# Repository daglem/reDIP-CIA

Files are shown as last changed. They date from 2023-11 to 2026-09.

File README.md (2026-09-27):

# reDIP CIA

## MOS 6520 PIA / MOS 6522 VIA / MOS 6526/8520/8521 CIA FPGA replacement
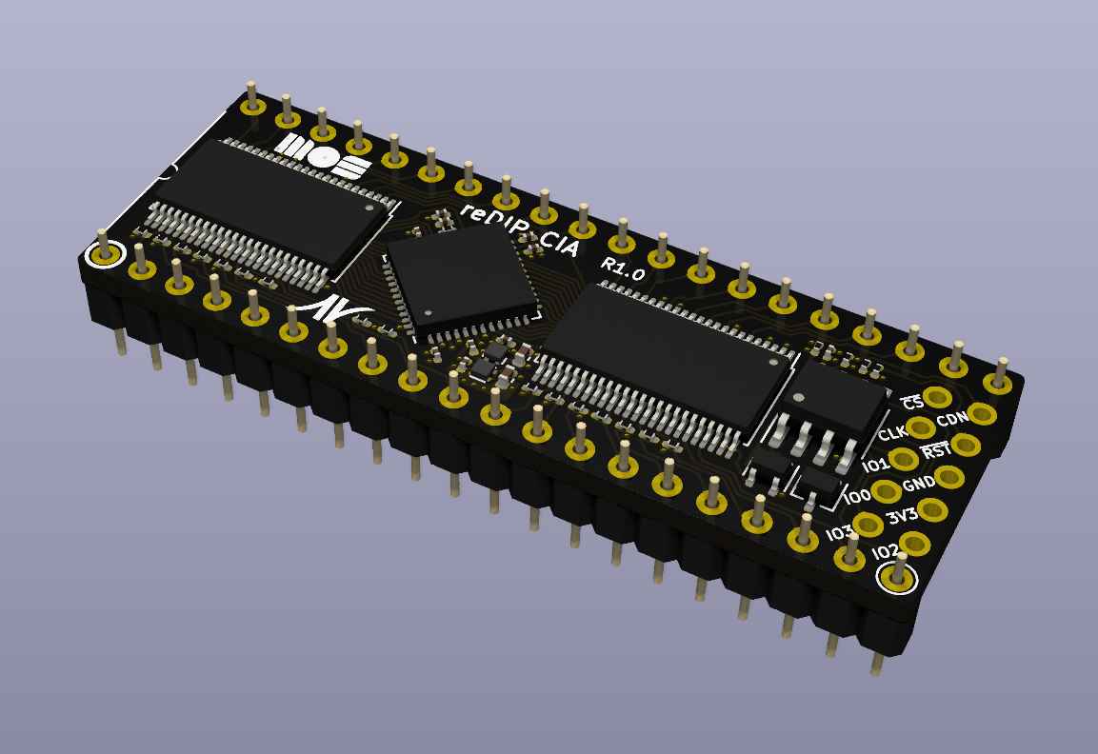
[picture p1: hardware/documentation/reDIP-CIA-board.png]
Board


## Overview
The reDIP CIA is an open source FPGA board which combines the following in a
DIP-40 size package:

* Lattice iCE5LP1K FPGA
* 1Mbit FLASH
* 5V tolerant I/O

The reDIP CIA provides an open source hardware platform for MOS 6520 PIA /
MOS 6522 VIA / MOS 6526/8520/8521 CIA replacements.

Designs for the iCE5LP1K FPGA can be processed by
[yosys](https://github.com/YosysHQ/yosys/) and
[nextpnr](https://github.com/YosysHQ/nextpnr/).

## I/O interfaces

### DIP-40 header pins:

* 5V input
* 35 FPGA GPIO
* 3 FPGA open-drain I/O
* GND

All FPGA header I/O is 5V tolerant, and can drive 5V TTL.

### SPI / programming header:

A separate header footprint is provided for (Q)SPI flash programming, with
pinout borrowed from the
[iCEBreaker Bitsy](https://codeberg.org/icebreaker-fpga/icebreaker).

## MOS 6526/8521 and MOS 8520 CIA compatibility

The board is fully pin compatible with the venerable MOS 6526/8521 and MOS 8520
CIA chips.

Cycle accurate emulation of the MOS 6526/8521 and MOS 8520 CIA chips has been
implemented in [gateware](gateware/CIA/), configurable via [software](software/).

## MOS 6522 VIA compatibility

Cycle accurate emulation of the MOS 6522 VIA chip has been implemented in
[gateware](gateware/VIA/).

## MOS 6520 PIA compatibility

Cycle accurate emulation of the MOS 6520 PIA chip has been implemented in
[gateware](gateware/PIA/).

## Thanks

The gateware implementations would not have been possible without the
[outstanding work](https://6502.org/forum/viewtopic.php?t=7427) on varius MOS
chips by Frank "androSID" Wolf and Dieter "ttlworks" Müller.

Wagner Rodriguez has tested the 8520 CIA implementation with the [Versatile
Amiga Testprogram](https://aminet.net/package/util/misc/VATestprogram).

Mateusz Nalewajski has hunted down and fixed two bugs while working on
integrating the VIA gateware in
[icepi-zero-c64](https://github.com/m1nl/icepi-zero-c64).

André Fachat has tested the VIA and PIA implementations with his [PET PIA and
VIA test suite](https://github.com/fachat/pet_viapia_tests).

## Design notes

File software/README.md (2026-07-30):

# reDIP CIA software

## CIA model configuration
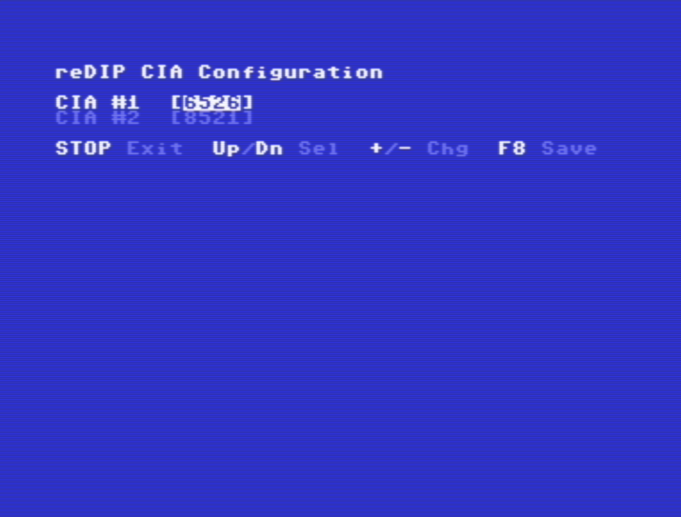
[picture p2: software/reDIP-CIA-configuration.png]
Configuration


The supplied [C64 program](cia-config.prg) can be used to select between MOS6526 and MOS8521 emulation for reDIP CIA boards in C64 and C128 machines.

The configuration is stored in the on-board flash chips.

The detected chip model is also displayed for original CIA chips.

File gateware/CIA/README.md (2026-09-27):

# reDIP CIA gateware

## Description

The reDIP CIA FPGA gateware provides cycle exact CIA emulation for the
[reDIP CIA](https://github.com/daglem/reDIP-CIA) hardware.

The gateware implementation is based on the excellent schematics of the
[MOS 8520](https://6502.org/forum/viewtopic.php?f=4&t=7368) and
[MOS 8521](https://6502.org/forum/viewtopic.php?f=4&t=7418) chips provided by
Frank "androSID" Wolf and Dieter "ttlworks" Müller.

Please note that the internal pullups for CNT, /FLAG, SP, and TOD in a real
8520 chip are only emulated by weak ~100k internal FPGA pullups.

By default, emulation of MOS 6526/8521 and MOS 8520 CIA chips is configurable
via [software](/software/), initially
configured as MOS 8521.

The emulation can alternatively be locked down at build time via one of

* `make MOS6526`
* `make MOS8521`
* `make MOS8520`

With projects in mind which use the reDIP CIA core gateware as part of a larger
whole to emulate the Commmodore 64, there is also an option to disable code for
the MOS 8520 (used in Commodore Amiga computers and 1581 disk drives). This
frees up some FPGA resources:

* `make NO_MOS8520`

## Installation

The gateware is built via `make` (see above) and may be installed on the reDIP
CIA hardware e.g. using an
[FTDI cable](https://ftdichip.com/products/c232hm-ddhsl-0-2/).

The gateware can be installed via `make prog`, which programs the on-board
flash chip via `iceprog`. Note that this makes configurable gateware generated
by `make` or `make NO_MOS8520` default to MOS 8521. The default can
alternatively be specified via one of

* `make prog-MOS6526`  # C64, SX-64, Ultimax
* `make prog-MOS8521`  # C64, C128, 1570, 1571
* `make prog-MOS8520`  # Amiga, 1581

## License

This gateware is part of reDIP CIA, a MOS 6526/8520/8521 CIA FPGA emulation
platform.\
Copyright (C) 2025 - 2026  Dag Lem \<resid@nimrod.no\>

The source describes Open Hardware and is licensed under the CERN-OHL-S v2.

You may redistribute and modify the source and make products using it under
the terms of the [CERN-OHL-S v2](https://ohwr.org/cern_ohl_s_v2.txt).

This source is distributed WITHOUT ANY EXPRESS OR IMPLIED WARRANTY,
INCLUDING OF MERCHANTABILITY, SATISFACTORY QUALITY AND FITNESS FOR A
PARTICULAR PURPOSE. Please see the CERN-OHL-S v2 for applicable conditions.

Source location:
[https://github.com/daglem/reDIP-CIA](https://github.com/daglem/reDIP-CIA)

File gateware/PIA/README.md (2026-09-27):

# reDIP PIA gateware

## Description

The reDIP PIA FPGA gateware provides cycle exact PIA emulation for the
[reDIP CIA](https://github.com/daglem/reDIP-CIA) hardware.

The gateware implementation is based on the excellent schematics of the
[MOS 6520](https://6502.org/forum/viewtopic.php?f=4&t=7425) chip provided by
Frank "androSID" Wolf and Dieter "ttlworks" Müller.

Please note that the internal pullup for CA2 in a real PIA chip is only
emulated by a weak ~100k internal FPGA pullup.

## Installation

The gateware is built via `make` and may be installed on the reDIP CIA hardware
e.g. via `make prog` using an
[FTDI cable](https://ftdichip.com/products/c232hm-ddhsl-0-2/).

## License

This gateware is part of reDIP CIA, a MOS PIA/VIA/CIA FPGA emulation
platform.\
Copyright (C) 2025 - 2026  Dag Lem \<resid@nimrod.no\>

The source describes Open Hardware and is licensed under the CERN-OHL-S v2.

You may redistribute and modify the source and make products using it under
the terms of the [CERN-OHL-S v2](https://ohwr.org/cern_ohl_s_v2.txt).

This source is distributed WITHOUT ANY EXPRESS OR IMPLIED WARRANTY,
INCLUDING OF MERCHANTABILITY, SATISFACTORY QUALITY AND FITNESS FOR A
PARTICULAR PURPOSE. Please see the CERN-OHL-S v2 for applicable conditions.

Source location:
[https://github.com/daglem/reDIP-CIA](https://github.com/daglem/reDIP-CIA)

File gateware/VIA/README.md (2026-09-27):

# reDIP VIA gateware

## Description

The reDIP VIA FPGA gateware provides cycle exact VIA emulation for the
[reDIP CIA](https://github.com/daglem/reDIP-CIA) hardware.

The gateware implementation is based on the excellent schematics of the
[MOS 6522](https://6502.org/forum/viewtopic.php?f=4&t=7241) chip provided by
Frank "androSID" Wolf and Dieter "ttlworks" Müller.

Please note that the internal pullups for CA2, CB1, and CB2 in a real VIA chip
are only emulated by weak ~100k internal FPGA pullups.

## Installation

The gateware is built via `make` and may be installed on the reDIP CIA hardware
e.g. via `make prog` using an
[FTDI cable](https://ftdichip.com/products/c232hm-ddhsl-0-2/).

## License

This gateware is part of reDIP CIA, a MOS PIA/VIA/CIA FPGA emulation
platform.\
Copyright (C) 2025 - 2026  Dag Lem \<resid@nimrod.no\>

The source describes Open Hardware and is licensed under the CERN-OHL-S v2.

You may redistribute and modify the source and make products using it under
the terms of the [CERN-OHL-S v2](https://ohwr.org/cern_ohl_s_v2.txt).

This source is distributed WITHOUT ANY EXPRESS OR IMPLIED WARRANTY,
INCLUDING OF MERCHANTABILITY, SATISFACTORY QUALITY AND FITNESS FOR A
PARTICULAR PURPOSE. Please see the CERN-OHL-S v2 for applicable conditions.

Source location:
[https://github.com/daglem/reDIP-CIA](https://github.com/daglem/reDIP-CIA)

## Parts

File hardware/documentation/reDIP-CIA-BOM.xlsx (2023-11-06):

Prj: | reDIP CIA |  |  |  |  |  |  | Board Qty: | 100
Co.: | Nimrod |  |  |  |  |  |  | Unit Cost: | $5.31
Prj date: | Mon 06 Nov 2023 10:01:10 PM CET |  |  |  |  |  |  | Total Cost: | $531.05 |  |  |  |  | $547.89 | 14 of 16 parts found |  |  |  |  | $536.10 | 15 of 16 parts found
$ date: | 2023-11-06 22:01:11
Global Part Info |  |  |  |  |  |  |  |  |  | Digi-Key |  |  |  |  |  | Mouser
Refs | Value | Desc | Notes | Footprint | Manf | Manf# | Qty | Unit$ | Ext$ | Avail | Purch | Unit$ | MOQ | Ext$ | Cat# | Avail | Purch | Unit$ | MOQ | Ext$ | Cat#
C1,C3 | 1uF | CAP CER 2.2uF 16V 10% X6S 0402 | 5V DC DERATED TO 1uF | C_0402_1005Metric | Murata | GRM155C81C225KE11D (https://www.murata.com/products/productdetail.aspx?partno=GRM155C81C225KE11D) | 200 | $0.088 | $17.66 | 66508 |  | $0.088 | 1 | $17.66 | 490-14595-1-ND (https://www.digikey.com/en/products/detail/murata-electronics/GRM155C81C225KE11D/4905093) | 57211 |  | $0.089 | 1 | $17.80 | 81-GRM155C81C225KE1D (https://no.mouser.com/ProductDetail/Murata-Electronics/GRM155C81C225KE11D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)
C2,C11 | 1uF | CAP CER 1uF 6.3V 20% X6S 0201 | 1.2V DC | C_0201_0603Metric | Murata | GRM033C80J105ME05D (https://www.murata.com/products/productdetail.aspx?partno=GRM033C80J105ME05D) | 200 | $0.054 | $10.80 | 1440111 |  | $0.078 | 1 | $15.56 | 490-13218-1-ND (https://www.digikey.com/en/products/detail/murata-electronics/GRM033C80J105ME05D/5877381) | 777764 |  | $0.054 | 1 | $10.80 | 81-GRM033C80J105ME5D (https://no.mouser.com/ProductDetail/Murata-Electronics/GRM033C80J105ME05D?qs=P8zzrVhehaso8Xg5mhsu3Q%3D%3D)
C4 | 1uF | CAP CER 2.2uF 10V 20% X5R 0201 | 3.3V DC DERATED TO 1uF | C_0201_0603Metric | Murata | GRM035R61A225ME01D (https://www.murata.com/products/productdetail.aspx?partno=GRM035R61A225ME01D) | 100 |  |  |  |  |  |  |  |  | NonStk |  |  | 10000 |  | 81-GRM035R61A225ME1D (https://no.mouser.com/ProductDetail/Murata-Electronics/GRM035R61A225ME01D?qs=pUKx8fyJudAGsIsikE8KgA%3D%3D)
C5-C10,C12 | 0.1uF | CAP CER 0.22uF 6.3V 20% X5R 0201 | C8: 1.2V DC DERATED TO 0.1uF C5-C7,C9,C10,C12: 3.3V DC DERATED TO 0.1uF | C_0201_0603Metric | Murata | GRM033R60J224ME90D (https://www.murata.com/products/productdetail.aspx?partno=GRM033R60J224ME90D) | 700 | $0.006 | $4.24 | 14729 |  | $0.006 | 1 | $4.24 | 490-11973-1-ND (https://www.digikey.com/en/products/detail/murata-electronics/GRM033R60J224ME90D/4904674) | 84464 |  | $0.007 | 1 | $4.90 | 81-GRM033R60J224ME9D (https://no.mouser.com/ProductDetail/Murata-Electronics/GRM033R60J224ME90D?qs=2W5sgKM%2F3704nCcQ8ai7mA%3D%3D)
D1 | BAS16W | DIODE Vf=715mV If=1mA | Replacement parts: BAS16W SOT-323/SC-70 | SOT-323_SC-70 | Diodes | BAS16W-7-F (https://www.diodes.com/assets/Datasheets/MMBD4148W_BAS16W.pdf) | 100 | $0.057 | $5.70 | 43800 |  | $0.073 | 1 | $7.33 | BAS16W-FDICT-ND (https://www.digikey.com/en/products/detail/diodes-incorporated/BAS16W-7-F/814988) | 21552 |  | $0.057 | 1 | $5.70 | 621-BAS16W-F (https://no.mouser.com/ProductDetail/Diodes-Incorporated/BAS16W-7-F?qs=Kn7RVldD90CMqWoFVqNeZQ%3D%3D)
J1,J2 | Conn_01x20 | CONN HDR CIRCULAR PIN 0.5mm 20 POS .100" GOLD MATING 3mm TAIL 3mm | Replacement parts: XKB X5511WV-20-C396D43-1220, other similar hdr circular pin ~0.5mm | PinHeader_1x20_P2.54mm_Vertical_Machined | XKB | X5511WV-20-C35D35-1000 (https://www.helloxkb.com/Home/Goods/goodsInfo/id/72370.html) | 200
R1-R16 | 4.7k | RES 4.7kΩ 50mW 5% 0201 |  | R_0201_0603Metric | Panasonic | ERJ1GNJ472C (https://industrial.panasonic.com/ww/products/pt/general-purpose-chip-resistors/models/ERJ1GNJ472C) | 1600 | $0.006 | $9.58 | 46 |  | $0.006 | 1 | $9.58 | P4.7AECT-ND (https://www.digikey.com/en/products/detail/panasonic-electronic-components/ERJ-1GNJ472C/2035803) | 273867 |  | $0.007 | 1 | $11.20 | 667-ERJ-1GNJ472C (https://no.mouser.com/ProductDetail/Panasonic/ERJ-1GNJ472C?qs=wTZ%2FFzl837bAY5BVQWuQGQ%3D%3D)
R17,R21 | 2.87k | RES 2.87kΩ 50mW 1% 0201 |  | R_0201_0603Metric | Panasonic | ERJ1GNF2871C (https://industrial.panasonic.com/ww/products/pt/general-purpose-chip-resistors/models/ERJ1GNF2871C) | 200 | $0.014 | $2.80 | 104225 |  | $0.019 | 1 | $3.80 | P122901CT-ND (https://www.digikey.com/en/products/detail/panasonic-electronic-components/ERJ-1GNF2871C/2036162) | 28194 |  | $0.014 | 1 | $2.80 | 667-ERJ-1GNF2871C (https://no.mouser.com/ProductDetail/Panasonic/ERJ-1GNF2871C?qs=nuXzIS8loXEy0KxXtNZxEA%3D%3D)
R18 | 100 | RES 100Ω 50mW 5% 0201 |  | R_0201_0603Metric | Panasonic | ERJ1GNJ101C (https://industrial.panasonic.com/ww/products/pt/general-purpose-chip-resistors/models/ERJ1GNJ101C) | 100 | $0.007 | $0.70 | 231675 |  | $0.013 | 1 | $1.25 | P123220CT-ND (https://www.digikey.com/en/products/detail/panasonic-electronic-components/ERJ-1GNJ101C/2035763) | 91154 |  | $0.007 | 1 | $0.70 | 667-ERJ-1GNJ101C (https://no.mouser.com/ProductDetail/Panasonic/ERJ-1GNJ101C?qs=nuXzIS8loXGN5So4aOOV1Q%3D%3D)
R19,R20 | 10k | RES 10kΩ 50mW 5% 0201 |  | R_0201_0603Metric | Panasonic | ERJ1GNJ103C (https://industrial.panasonic.com/ww/products/pt/general-purpose-chip-resistors/models/ERJ1GNJ103C) | 200 | $0.013 | $2.66 | 704515 |  | $0.013 | 1 | $2.66 | P123222CT-ND (https://www.digikey.com/en/products/detail/panasonic-electronic-components/ERJ-1GNJ103C/2035811) | 683736 |  | $0.014 | 1 | $2.80 | 667-ERJ-1GNJ103C (https://no.mouser.com/ProductDetail/Panasonic/ERJ-1GNJ103C?qs=nuXzIS8loXEEFlX40uqTHQ%3D%3D)
U1 | NCP115AMX120TCG | IC REG LDO 1.2V 300mA XDFN4 |  | CASE_711AJ_1.0x1.0mm_P0.65mm | onsemi | NCP115AMX120TCG (https://www.onsemi.com/pdf/datasheet/ncp115-d.pdf) | 100 | $0.118 | $11.80 | 7412 |  | $0.143 | 1 | $14.33 | NCP115AMX120TCGOSCT-ND (https://www.digikey.com/en/products/detail/onsemi/NCP115AMX120TCG/9829201) | 11436 |  | $0.118 | 1 | $11.80 | 863-NCP115AMX120TCG (https://no.mouser.com/ProductDetail/onsemi/NCP115AMX120TCG?qs=l7cgNqFNU1iSEavmMXBgHw%3D%3D)
U2 | NCP115AMX330TCG | IC REG LDO 3.3V 300mA XDFN4 |  | CASE_711AJ_1.0x1.0mm_P0.65mm | onsemi | NCP115AMX330TCG (https://www.onsemi.com/pdf/datasheet/ncp115-d.pdf) | 100 | $0.124 | $12.40 | 12836 |  | $0.143 | 1 | $14.33 | NCP115AMX330TCGOSCT-ND (https://www.digikey.com/en/products/detail/onsemi/NCP115AMX330TCG/9829207) | 26927 |  | $0.124 | 1 | $12.40 | 863-NCP115AMX330TCG (https://no.mouser.com/ProductDetail/onsemi/NCP115AMX330TCG?qs=l7cgNqFNU1j9mIi8Ii%2FRXw%3D%3D)
U3,U4 | SN74CBT16210CDGGR | IC BUS SWITCH TSSOP-48 | Replacement parts: SN74CBT16210DGGR | TSSOP-48_6.1x12.5mm_P0.5mm | TI | SN74CBT16210CDGGR (https://www.ti.com/lit/ds/symlink/sn74cbt16210c.pdf) | 200 |  |  | 20045 |  |  | 502 |  | 2156-SN74CBT16210CDGGR-ND (https://www.digikey.com/en/products/detail/texas-instruments/SN74CBT16210CDGGR/864166) | NonStk |  |  | 2000 |  | 595-SN74CBT16210CDGG (https://no.mouser.com/ProductDetail/Texas-Instruments/SN74CBT16210CDGGR?qs=PVVDbbWpW3LUOtG5S0DQpQ%3D%3D)
U5 | 74AHCT1G14 | IC SCHMITT-TRIGGER INVERTER | Replacement parts: 74AHCT1G14 SOT-353/SC-70-5 | SOT-353_SC-70-5 | Diodes | 74AHCT1G14SE-7 (https://www.diodes.com/assets/Datasheets/74AHCT1G14.pdf) | 100 | $0.077 | $7.70 | 74194 |  | $0.118 | 1 | $11.80 | 74AHCT1G14SE-7DICT-ND (https://www.digikey.com/en/products/detail/diodes-incorporated/74AHCT1G14SE-7/2711985) | 1287 |  | $0.077 | 1 | $7.70 | 621-74AHCT1G14SE-7 (https://no.mouser.com/ProductDetail/Diodes-Incorporated/74AHCT1G14SE-7?qs=MKoP7Oyr0W4E9AvHvgTtWw%3D%3D)
U6 | ICE5LP1K-SG48 | IC FPGA QFN-48 |  | QFN-48-1EP_7x7mm_P0.5mm_EP5.6x5.6mm | Lattice | ICE5LP1K-SG48ITR (https://www.latticesemi.com/Products/FPGAandCPLD/iCE40Ultra) | 100 | $4.225 | $422.50 | 2190 |  | $4.225 | 1 | $422.50 | 220-2155-1-ND (https://www.digikey.com/en/products/detail/lattice-semiconductor-corporation/ICE5LP1K-SG48ITR/5324261) | 4302 |  | $4.250 | 1 | $425.00 | 842-ICE5LP1K-SG48ITR (https://no.mouser.com/ProductDetail/Lattice/ICE5LP1K-SG48ITR?qs=ZwKJWZfDtNg6punXjA%252B0Og%3D%3D)
U7 | AT25EU0011A-SSHN | IC FLASH 1MBIT | Replacement parts: 1MBit SPI flash SOIC-8/SOP-8 | SOIC-8_3.9x4.9mm_P1.27mm | Renesas | AT25EU0011A-SSHN-T (https://www.renesas.com/us/en/document/dst/at25eu0011a-datasheet) | 100 | $0.225 | $22.50 | 3995 |  | $0.228 | 1 | $22.84 | 1695-AT25EU0011A-SSHN-TCT-ND (https://www.digikey.com/en/products/detail/renesas-electronics-operations-services-limited/AT25EU0011A-SSHN-T/14309093) | 3935 |  | $0.225 | 1 | $22.50 | 724-AT25EU0011ASSHNT (https://no.mouser.com/ProductDetail/Renesas-Dialog/AT25EU0011A-SSHN-T?qs=QNEnbhJQKvbVoO3jTCIuvg%3D%3D)
 |  |  |  |  |  |  |  | Total Purchase: | $0.00 | Buy here (https://www.digikey.com/ordering/shoppingcart) |  |  |  | $0.00 |  | Buy here (https://mouser.com/bom/) |  |  |  | $0.00
KiCost® v1.1.18 |  |  |  |  |  |  |  | Purchase description:

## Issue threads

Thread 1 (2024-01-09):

Question about IO and crystal

bwack, 2024-01-09:
Hi Dag. Nice project!
I wonder, I designed a similar board with same fpga as the icebreaker dev board iCE40UP5k, I had trouble figuring out if the RGB IOs are configurable for IO? Maybe it is different for the LP1K. I had trouble getting enough IO for the CIA. Also, will it load the flash without a crystal?
Just wondering. As you may know I made the VHDL6526, tested it with a custom cartridge that I programmed, but never made a PCB for it.
If you have tested this design, I'd like to try myself and use my cartridge to check it.

Hans

daglem, 2024-01-09:
Hi Hans!

Here is an example of instantiating iCE40UP5K RGB I/O primitives for both current drive and open-drain I/O in SystemVerilog (should be similar in VHDL): [sid_io.sv](https://github.com/daglem/reDIP-SID/blob/560d226374f3fd63918e0a475b99f2c5457aa53f/gateware/sid_io.sv#L177-L208)
Here I have used `SB_IO` for the open-drain I/O, which at least in Yosys works the same as `SB_IO_OD`, except of course that there are no internal pull-ups, and that you need external pull-ups to output a logical '1'.
This should work the same in the iCE5LP1K, however I haven't tested that yet.

The reDIP-CIA board implements ideas I had to get 38 usable I/O out of the aforementioned FPGAs for DIP-40 replacements, without using any muxes (unlike the VHDL6526), and while still being reprogrammable (unlike the J-CIA, IIUC).

I got a kick in the butt from @sajattack to actually design this, since he wanted replacements for [6530 RRIOT](https://github.com/daglem/reDIP-RIOT) chips in KIM-1 replicas, see his project [yo6530](https://github.com/sajattack/yo6530).
He has gotten reDIP-RIOT boards assembled by PCBCart, and so far they seem to work as intended. Configuration from flash doesn't depend on an external crystal. He had to do a last minute BOM change to replace the iCE5LP1K with iCE40UP5K, since I found out that the cheaper iCE5LP1K, while pin compatible and seemingly *very* similar, lacks configurable pull-up resistors (PULLUP_RESISTOR). Hence the external pull-up resistors on the reDIP-CIA.

Other than this, the design has not been tested, and unfortunately I won't get around to have any boards made in a while, which I could otherwise have sent to you. As it currently stands, if you want to try it out, you'll have to take your chances and have some boards made yourself.

bwack, 2024-01-10:
Thank you Dag. I will give it a go. I'll build one up and start testing bitstreams on it!

daglem, 2024-01-10:
Good luck! :crossed_fingers:
Let me know how it goes!

Closed 2024-01-09.

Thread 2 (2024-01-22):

Where is the gateware source?

mankeli, 2024-01-22:
I can only see the pin definitions, but seems that all actual verilog is missing.

daglem, 2024-01-22:
I have not implemented any gateware yet - for now it's just the hardware design, in case anyone wants to experiment with that.

root42, 2025-05-30:
Another CIA project just got its source released. It‘s for a different FPGA but might give this project a headstart:
https://www.forum64.de/index.php?thread/155909-cia-6526-8521-ersatz-vorstellung-und-das-ende-des-projekts/

Closed 2024-01-22.

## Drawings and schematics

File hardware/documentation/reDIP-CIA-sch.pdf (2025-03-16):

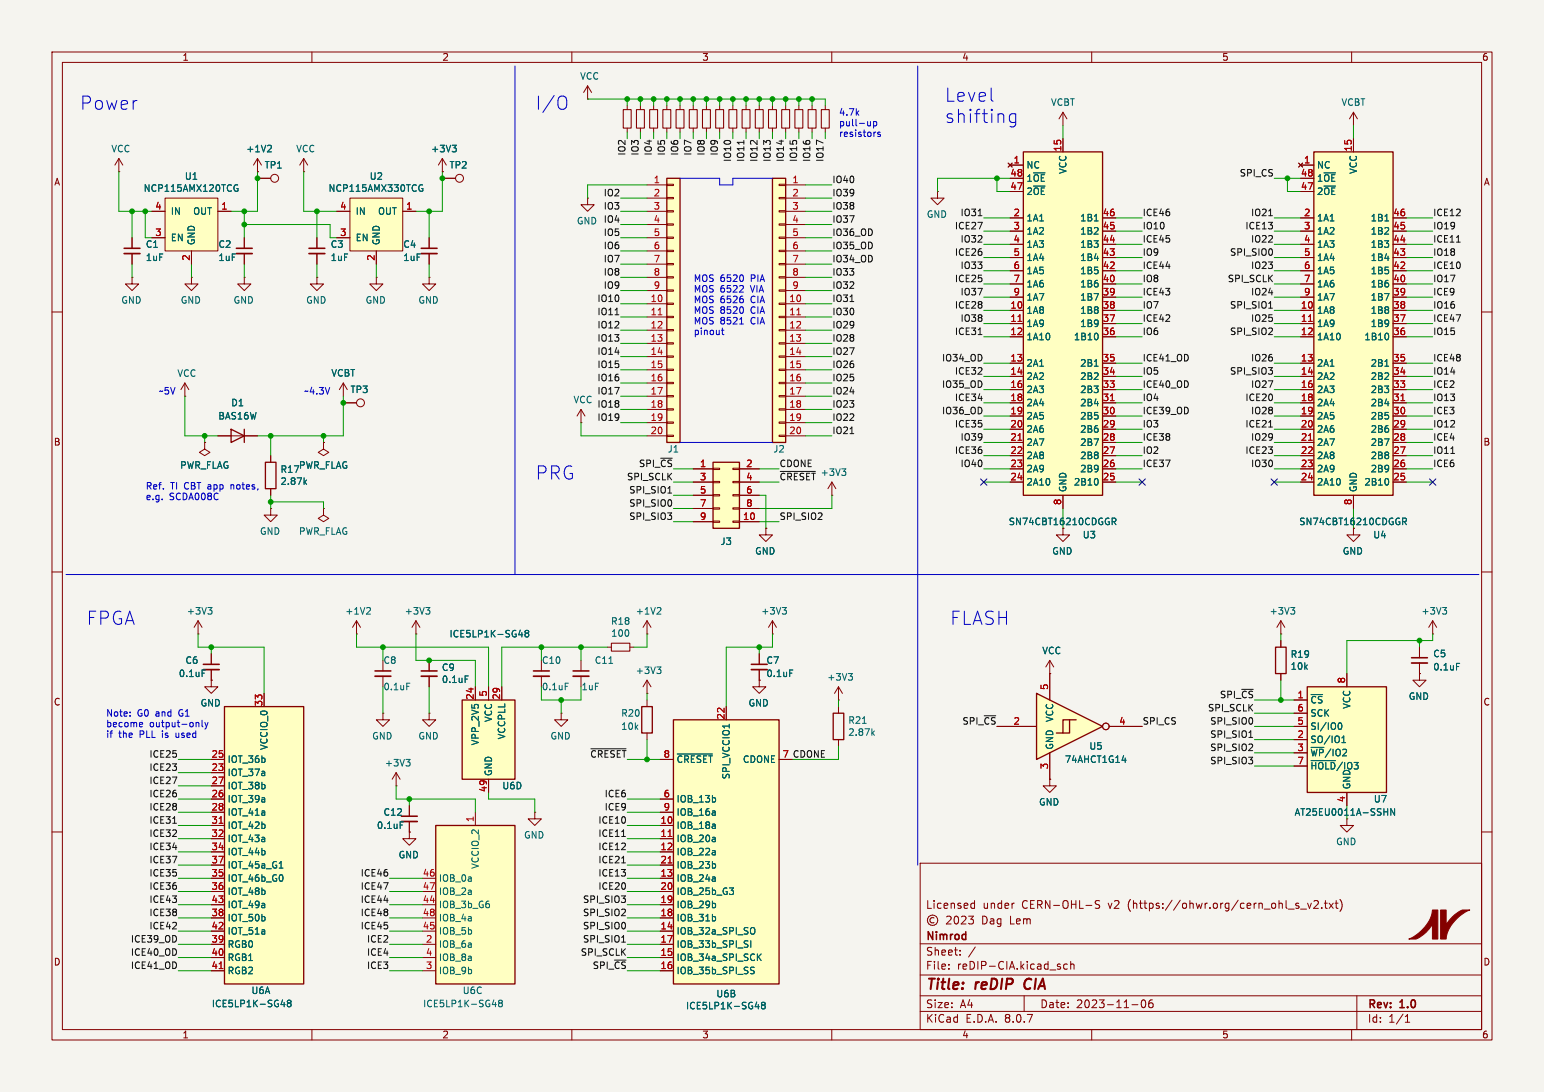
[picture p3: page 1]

shifting Power Note: G0 and G1
IN 4 PWR_FLAG R17

8 U7 AT25EU0011A-SSHN GND GND GND

4 SI/IO0 5 SCK 6 ~{HOLD}/IO3 7 VCC

File: reDIP-CIA.kicad_sch Sheet: / Nimrod

Id: 1/1 Title: reDIP CIA

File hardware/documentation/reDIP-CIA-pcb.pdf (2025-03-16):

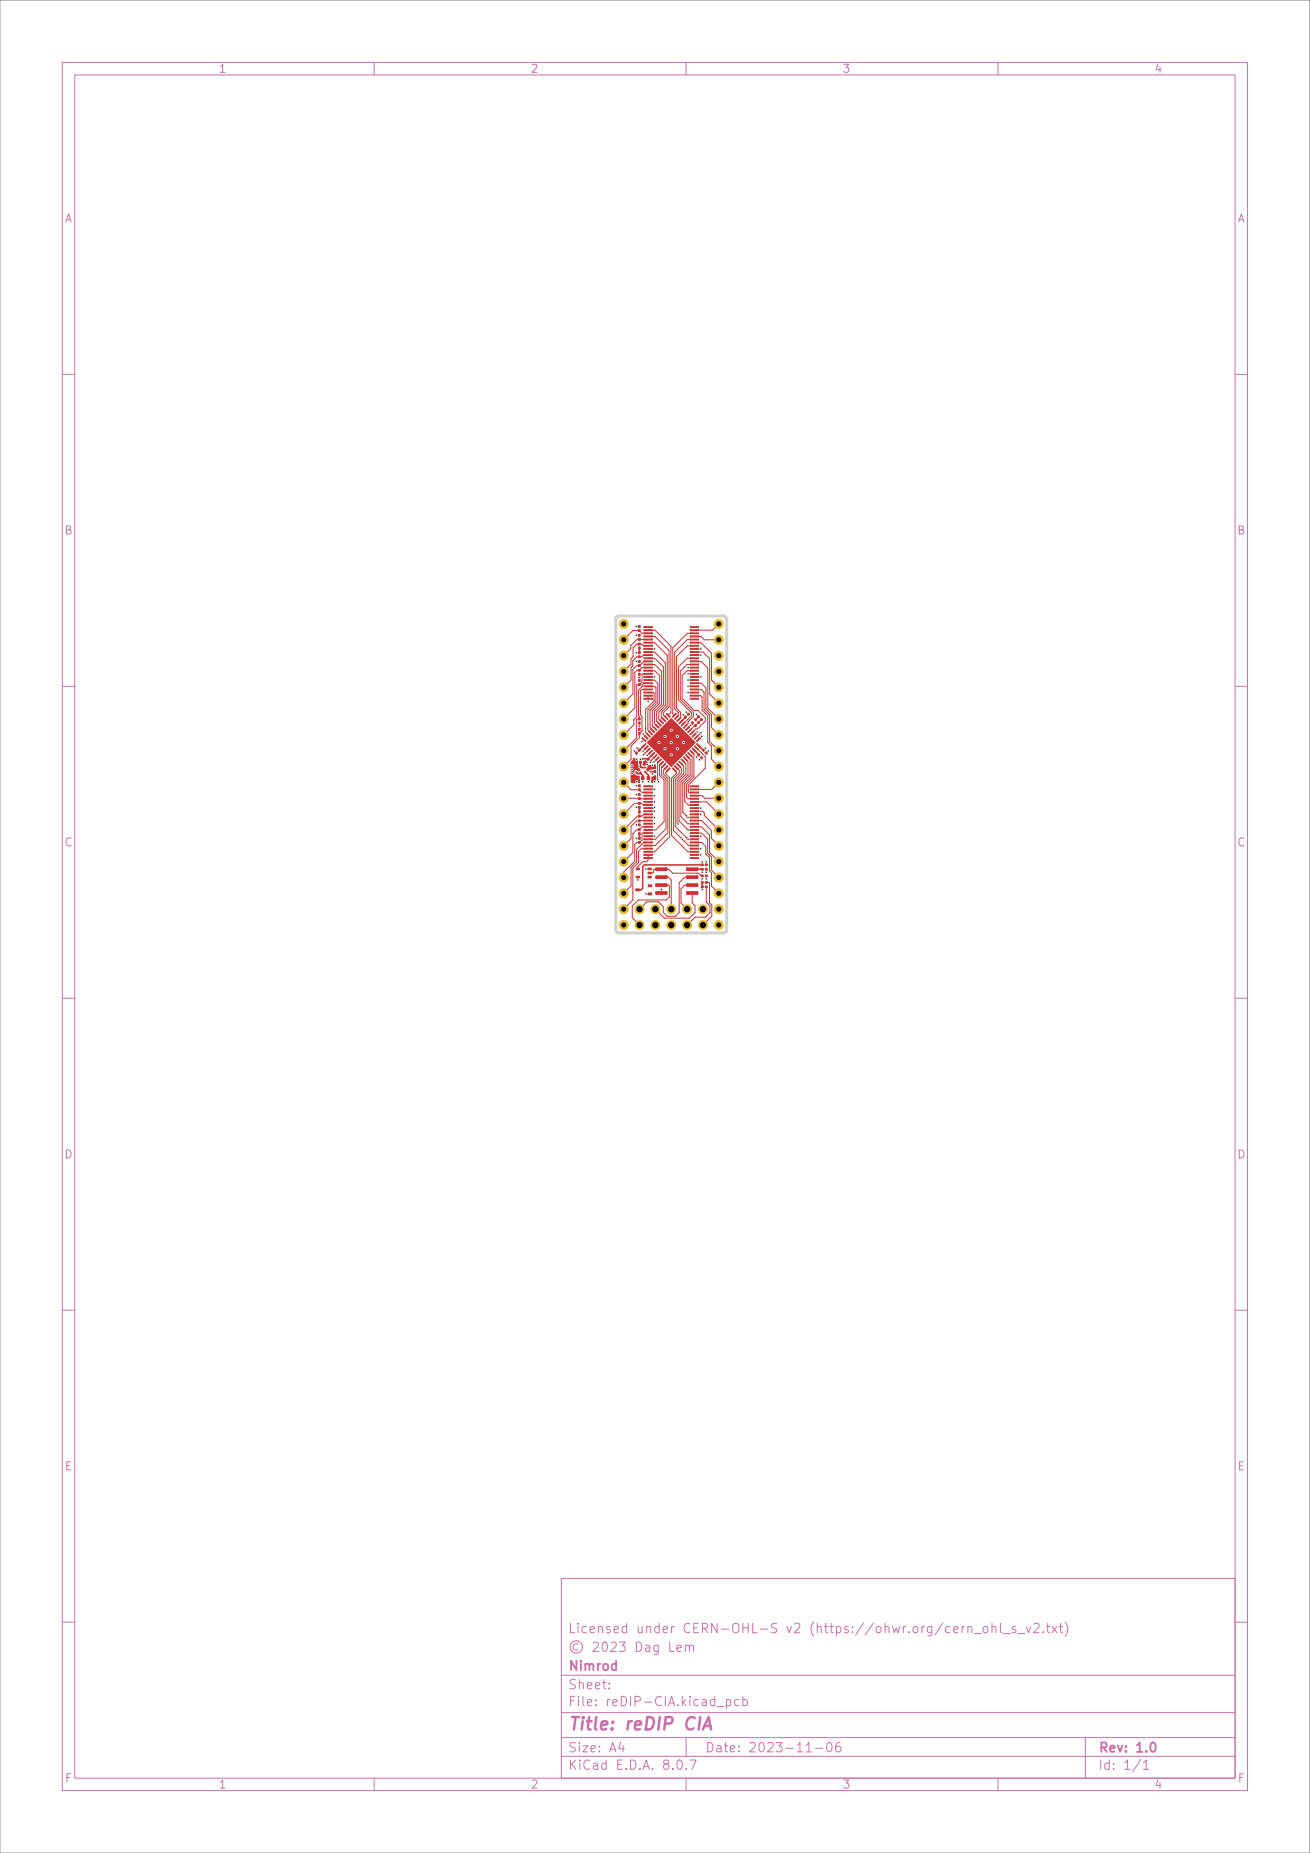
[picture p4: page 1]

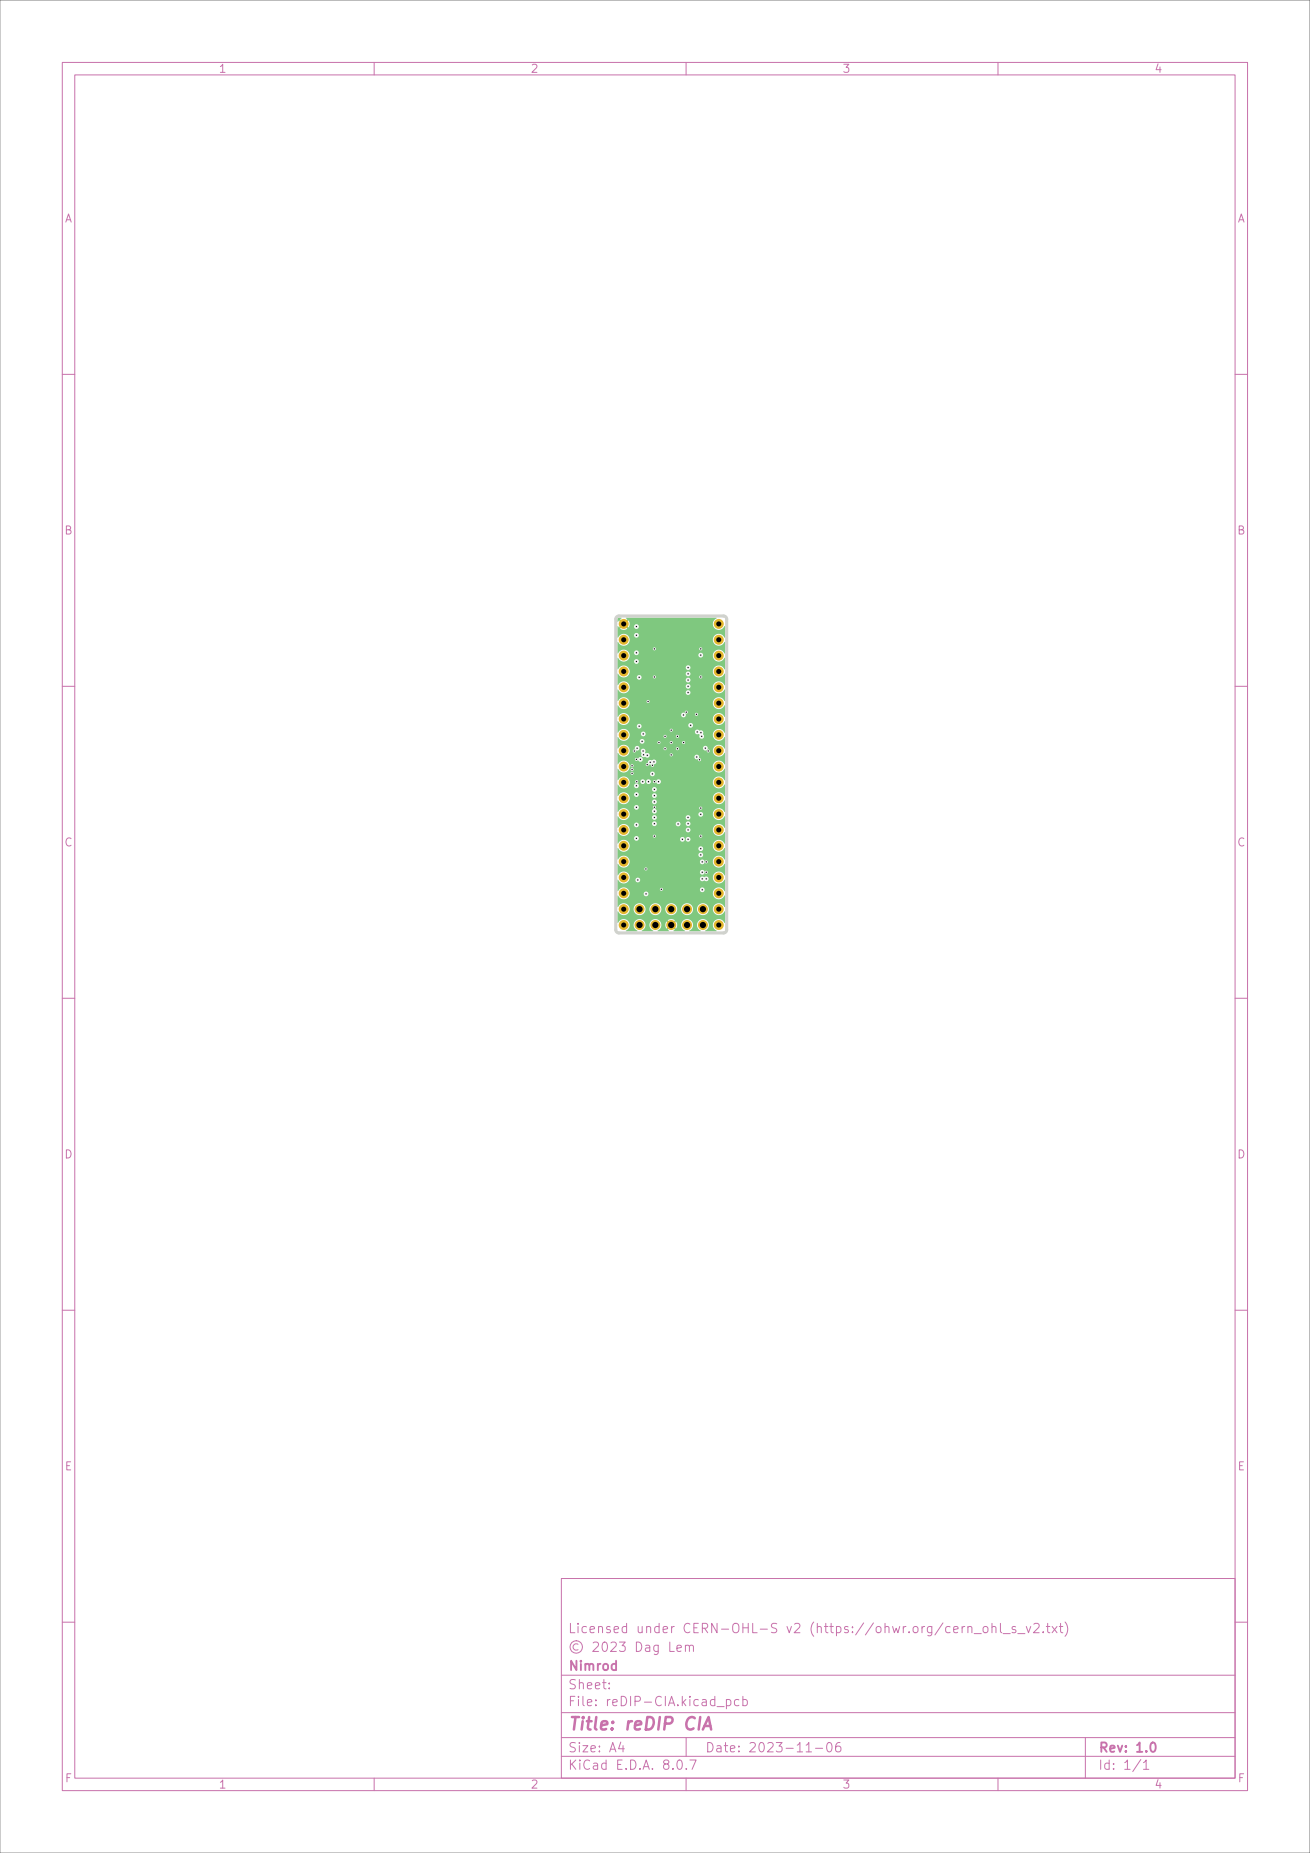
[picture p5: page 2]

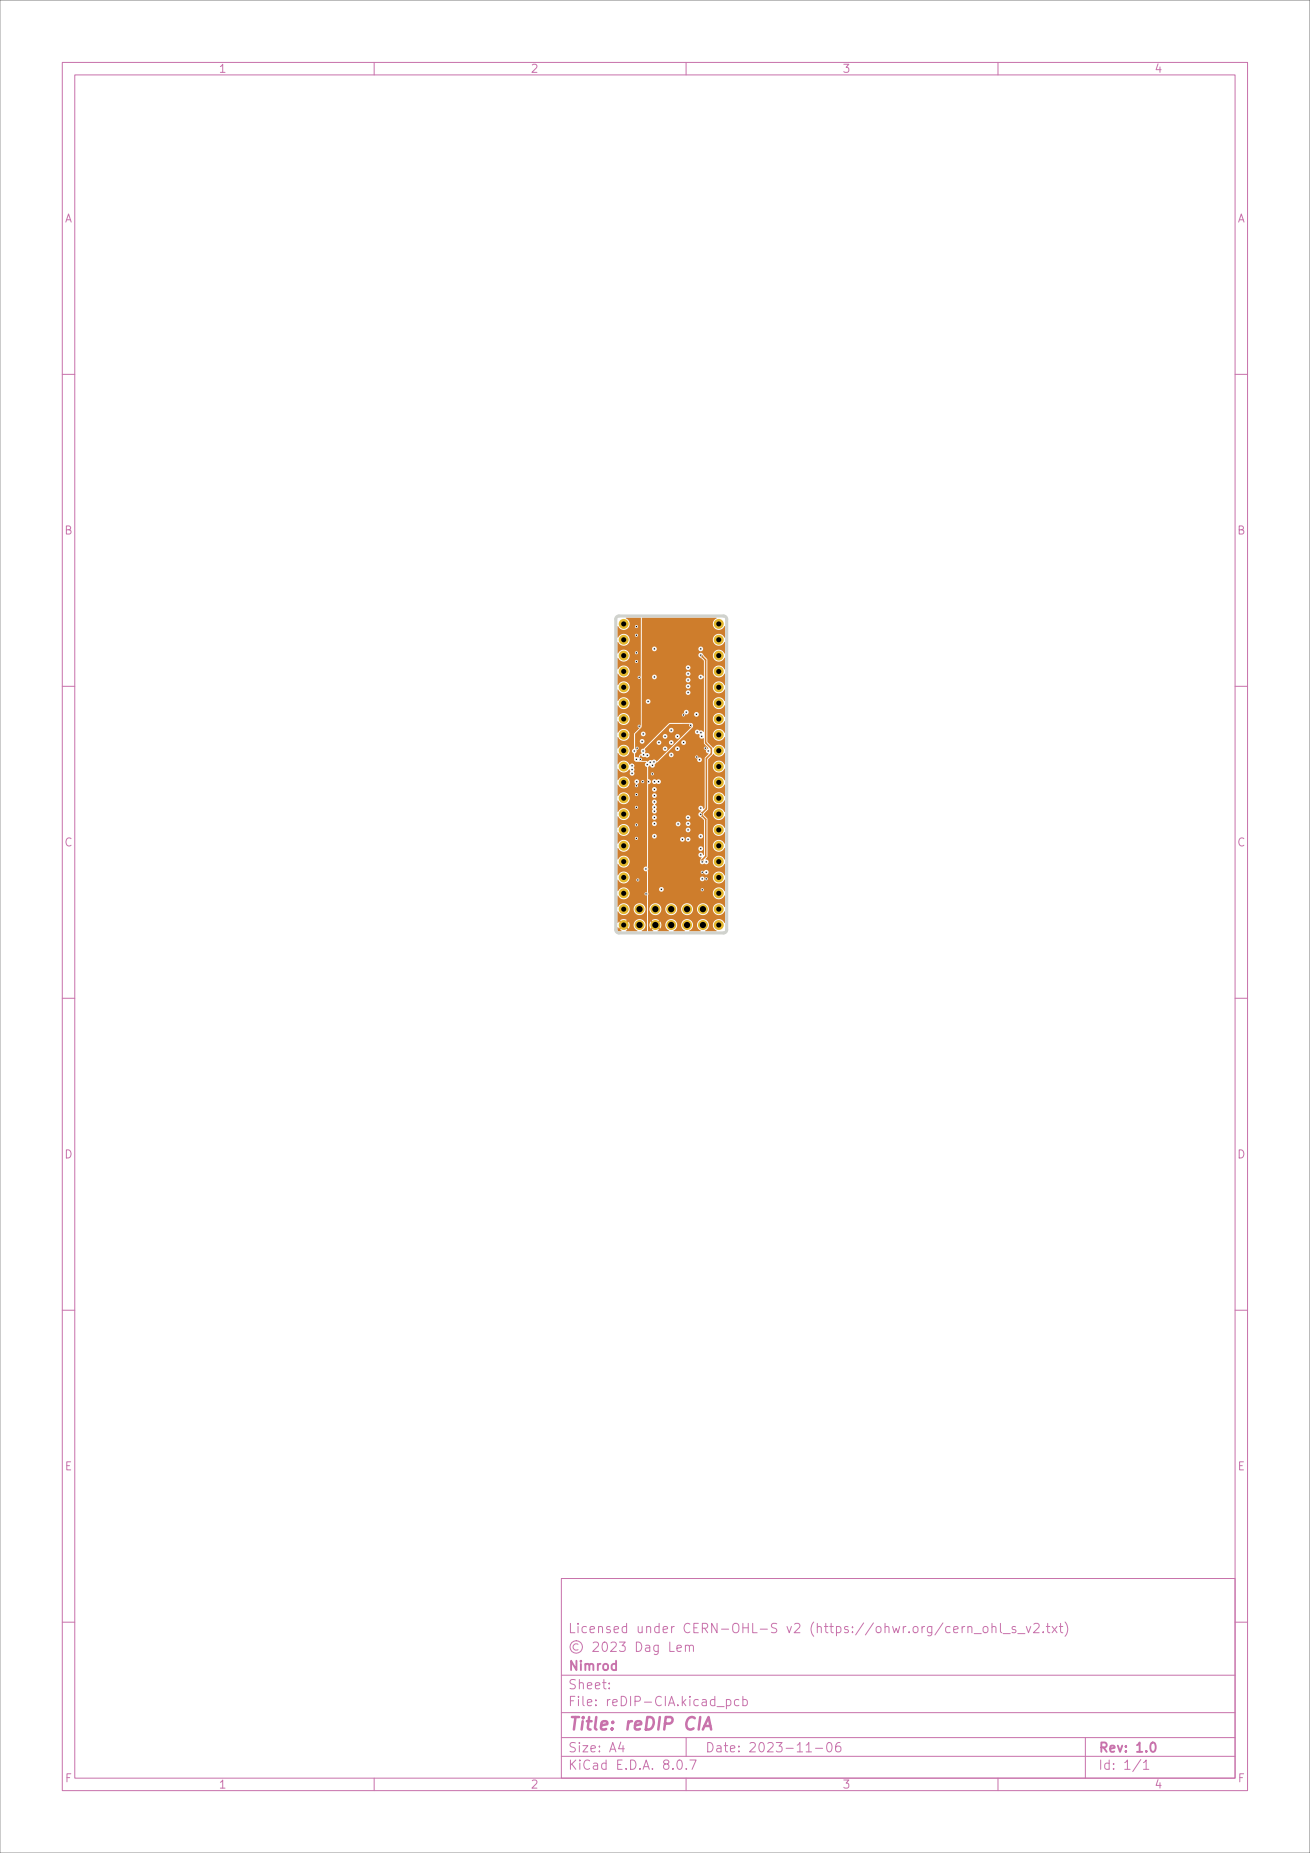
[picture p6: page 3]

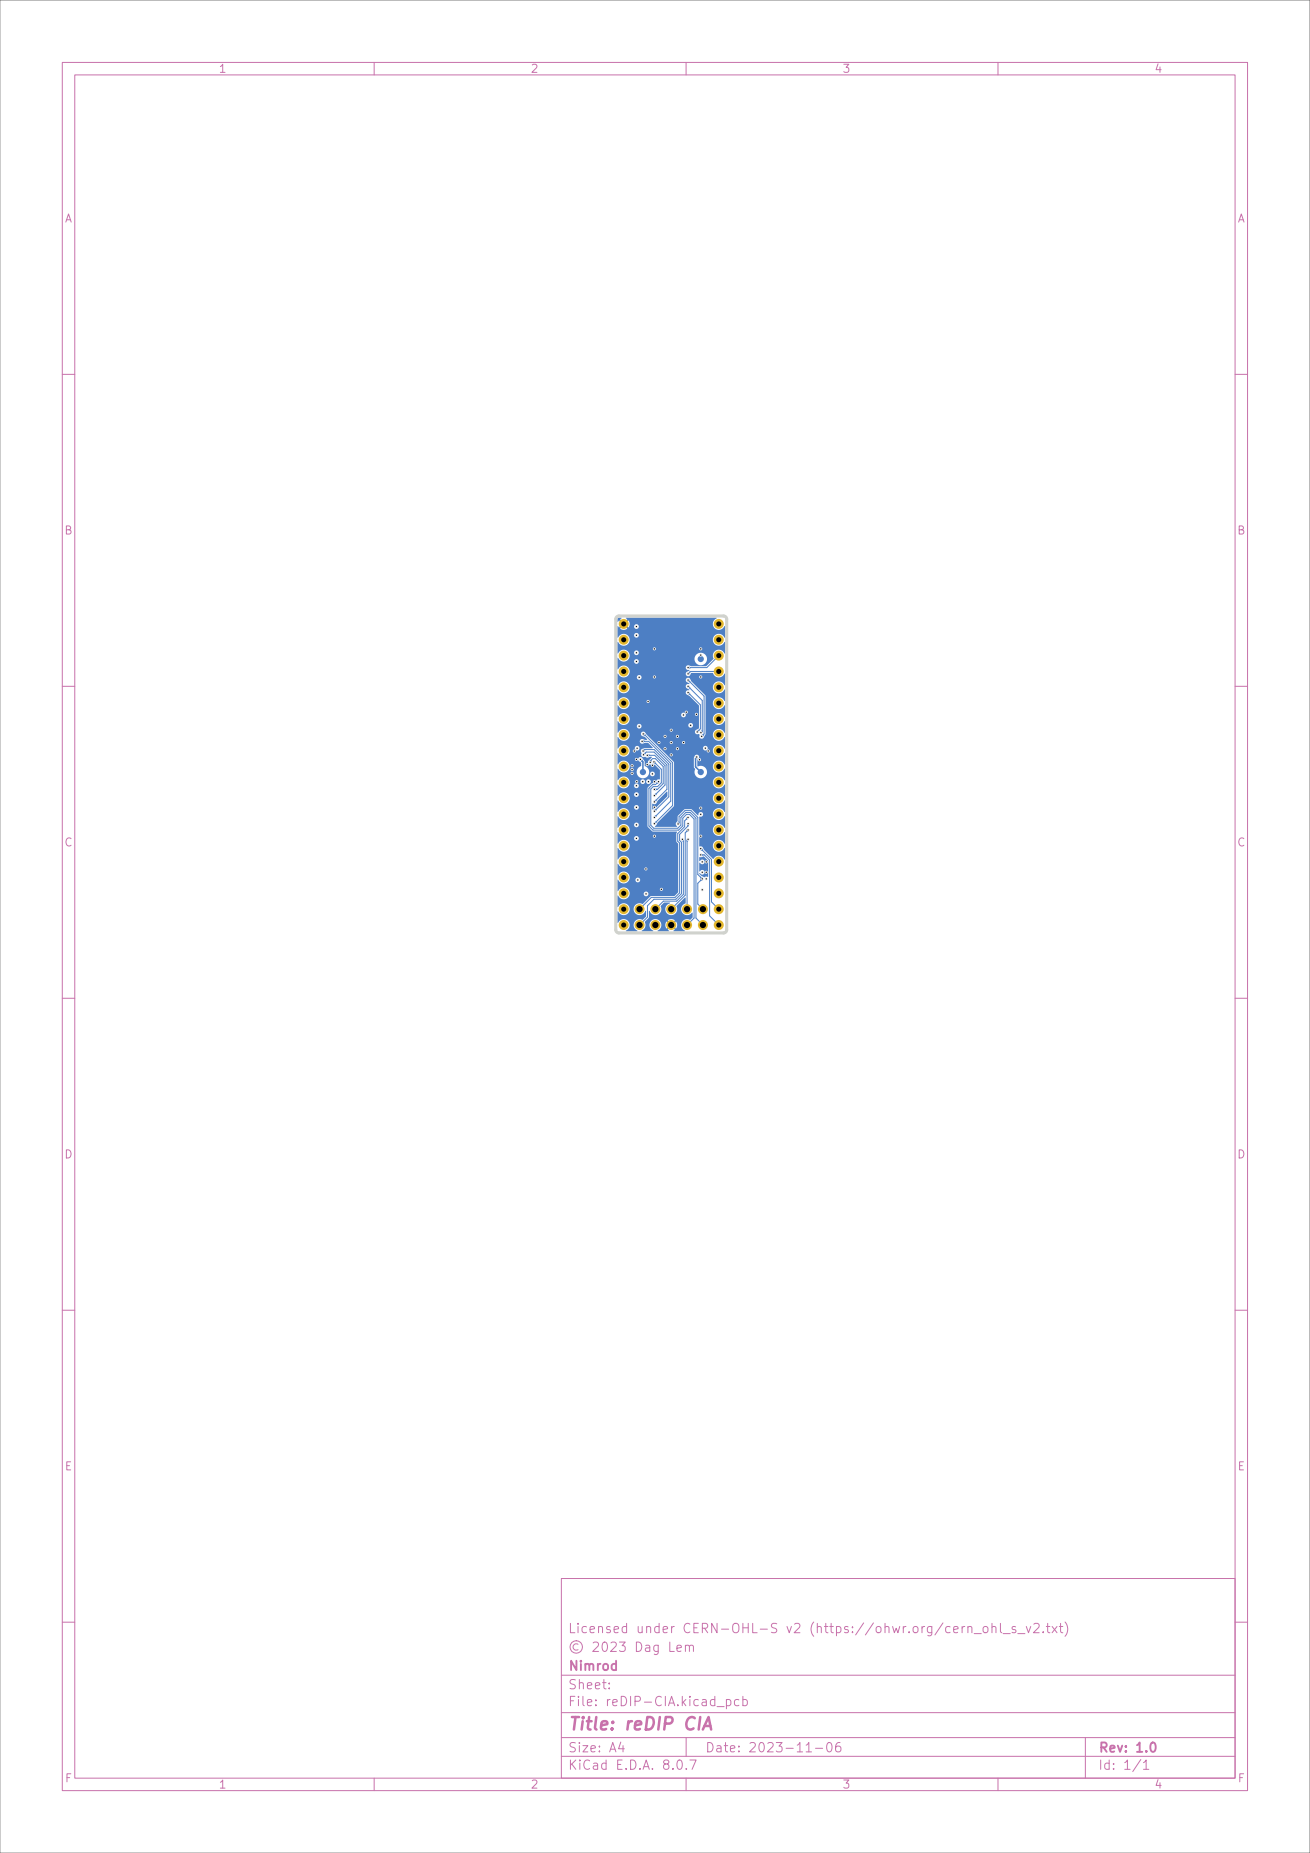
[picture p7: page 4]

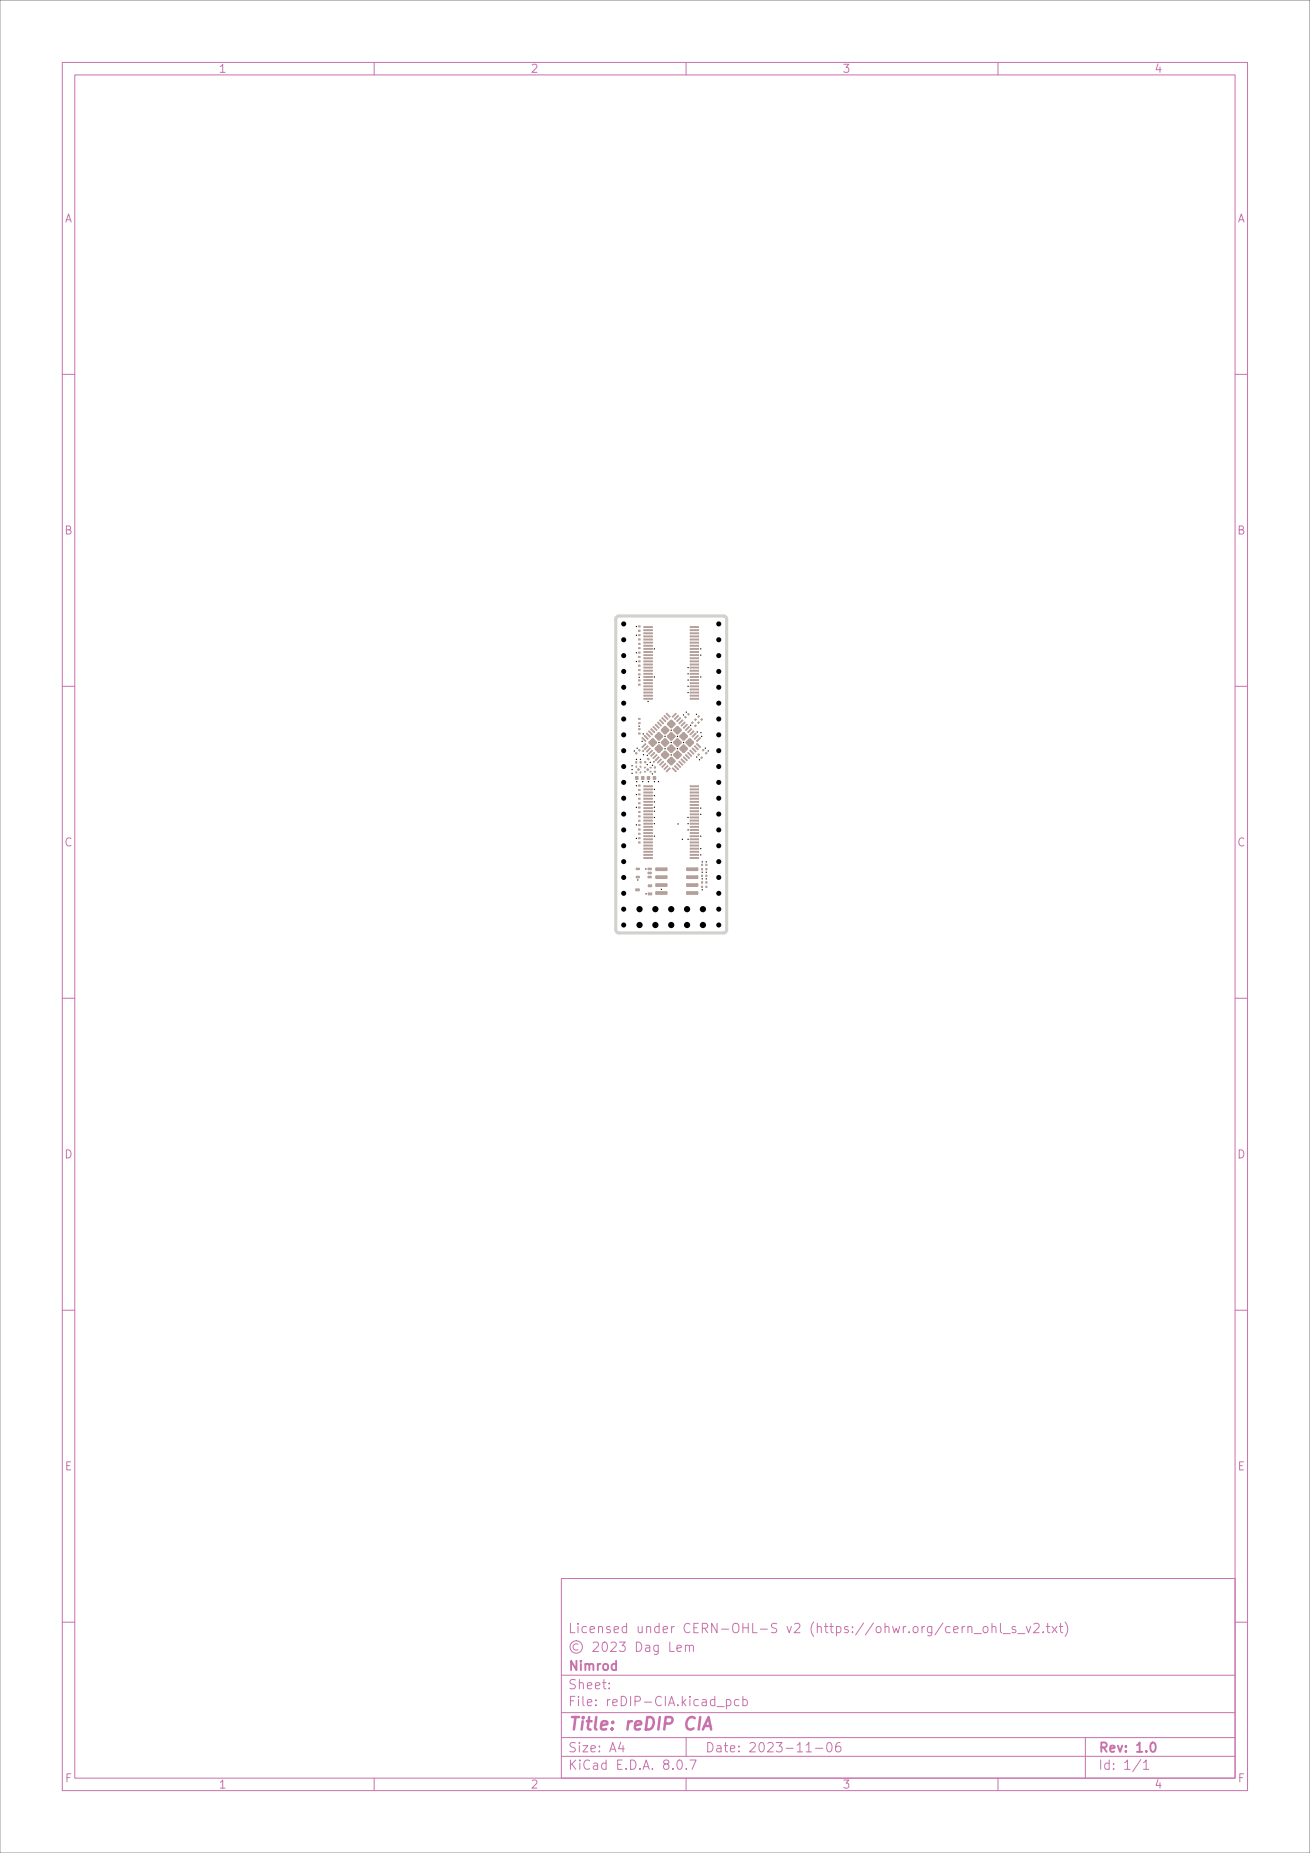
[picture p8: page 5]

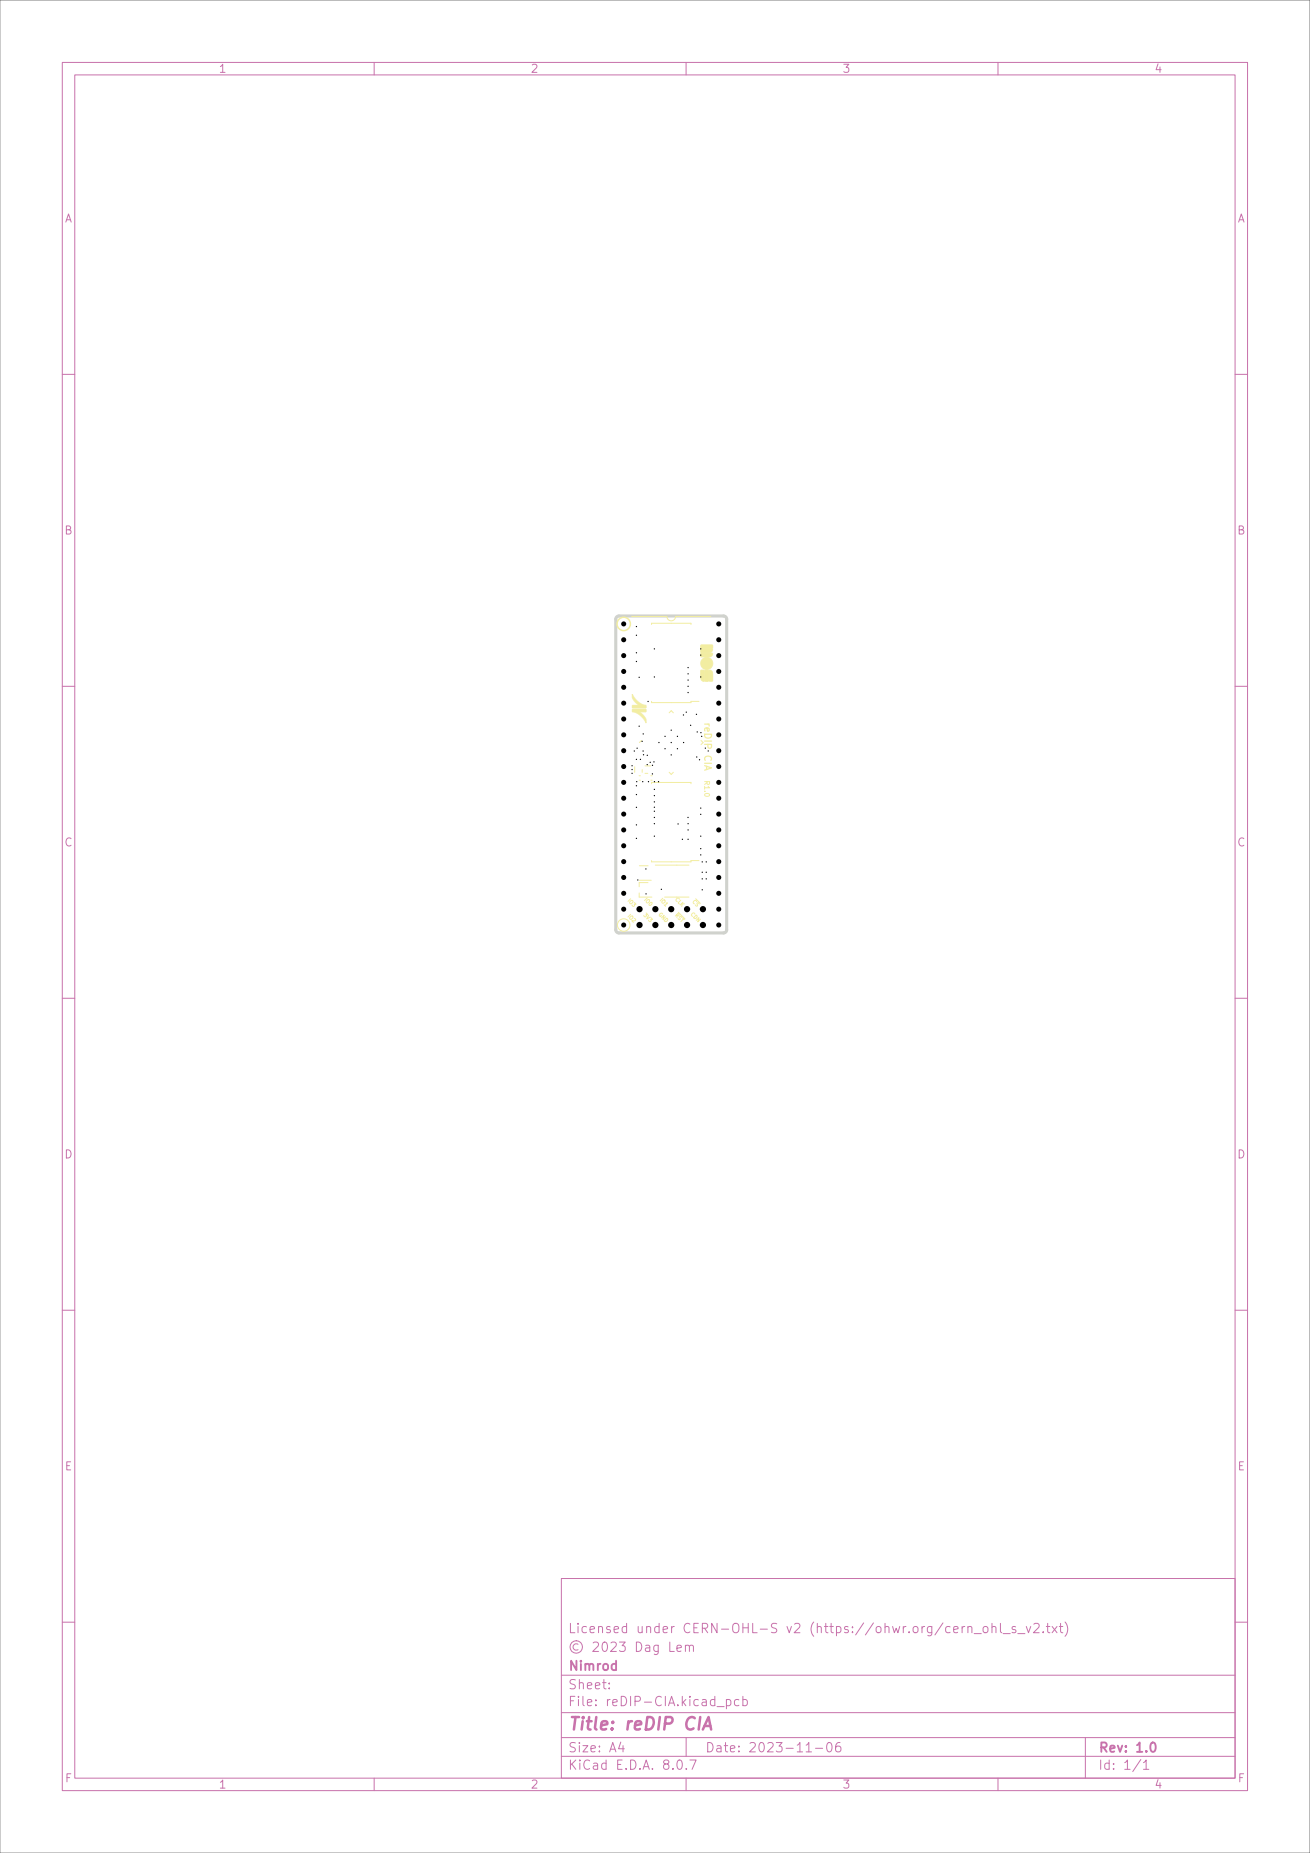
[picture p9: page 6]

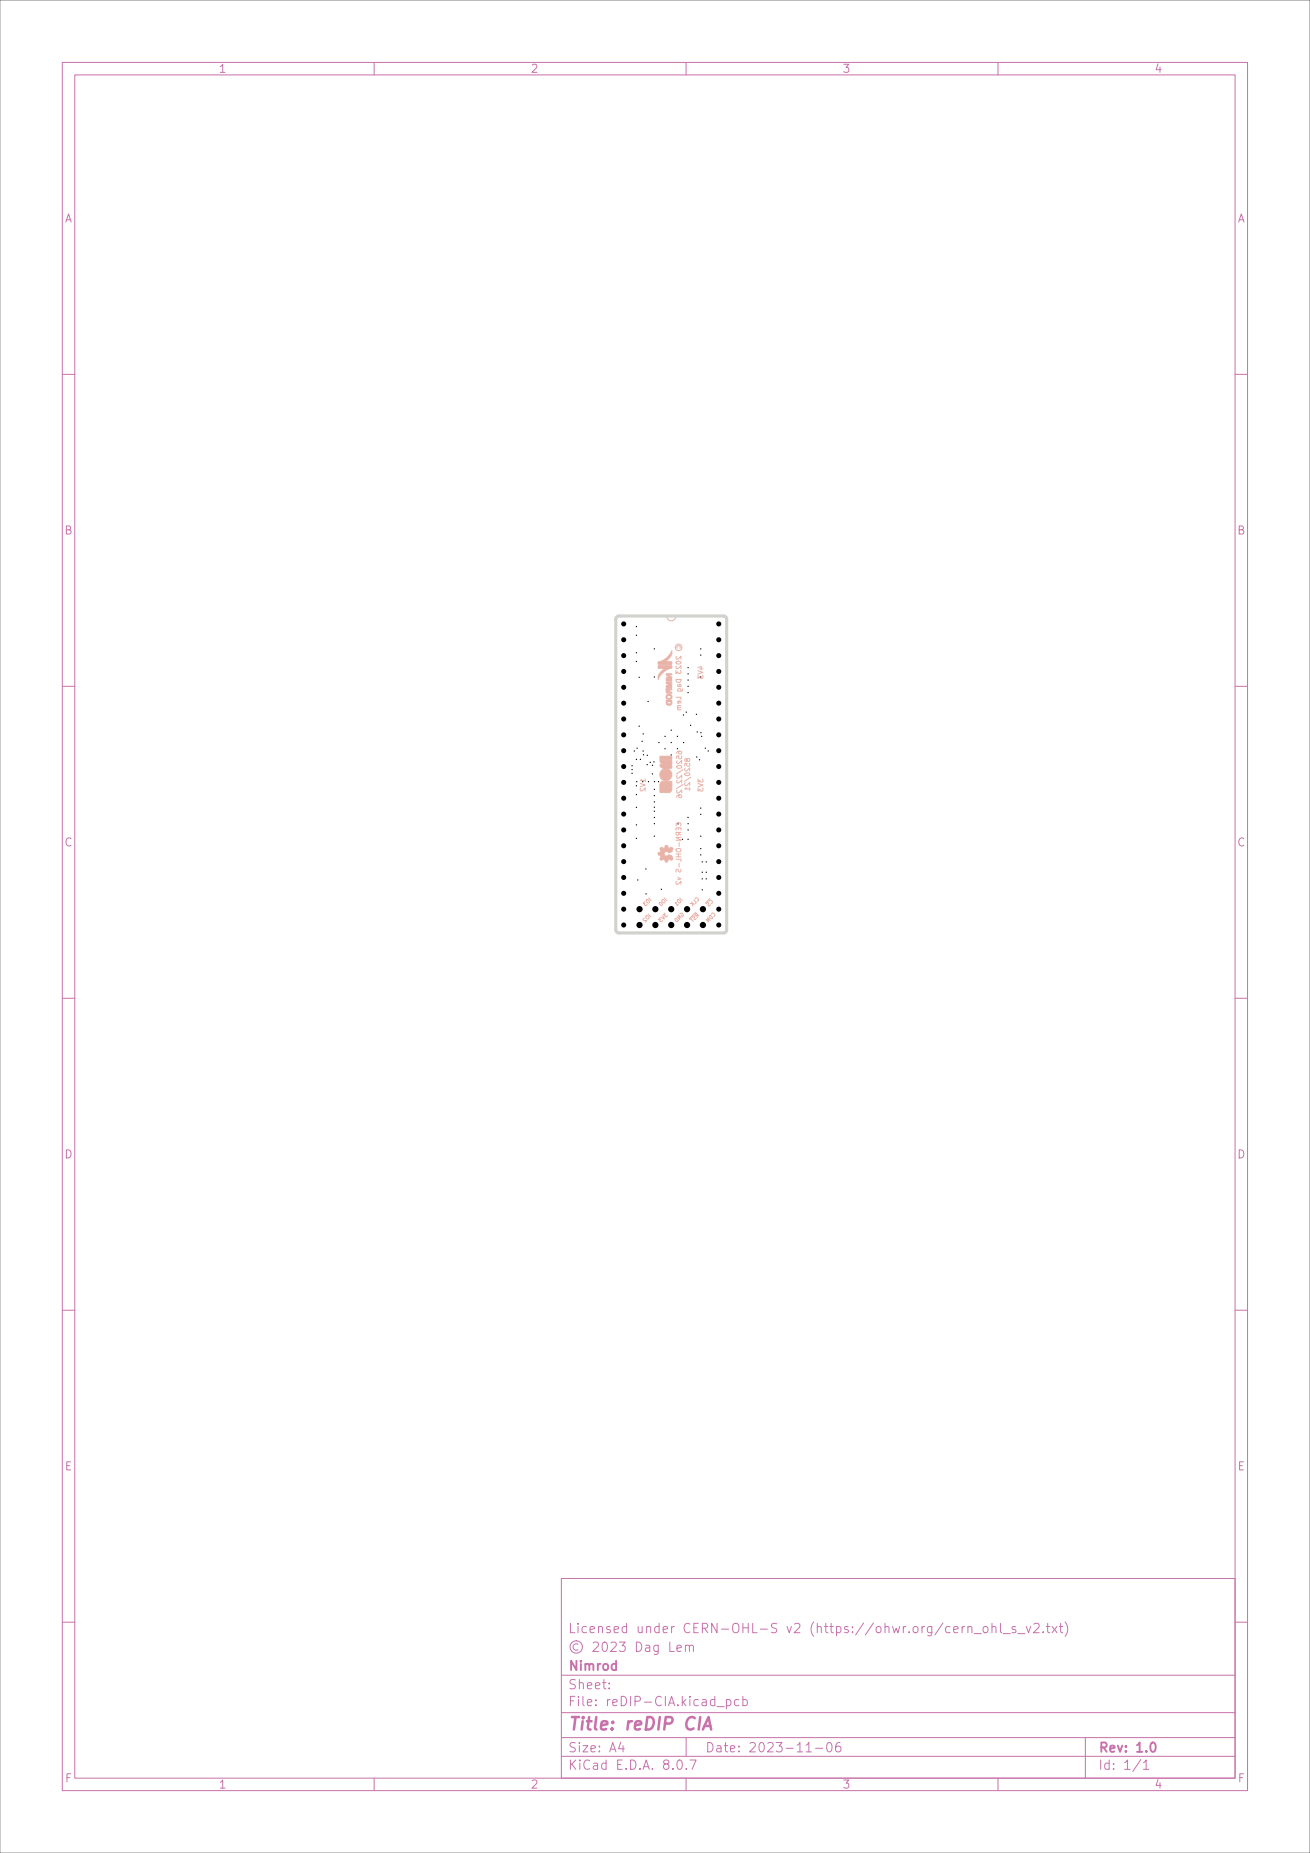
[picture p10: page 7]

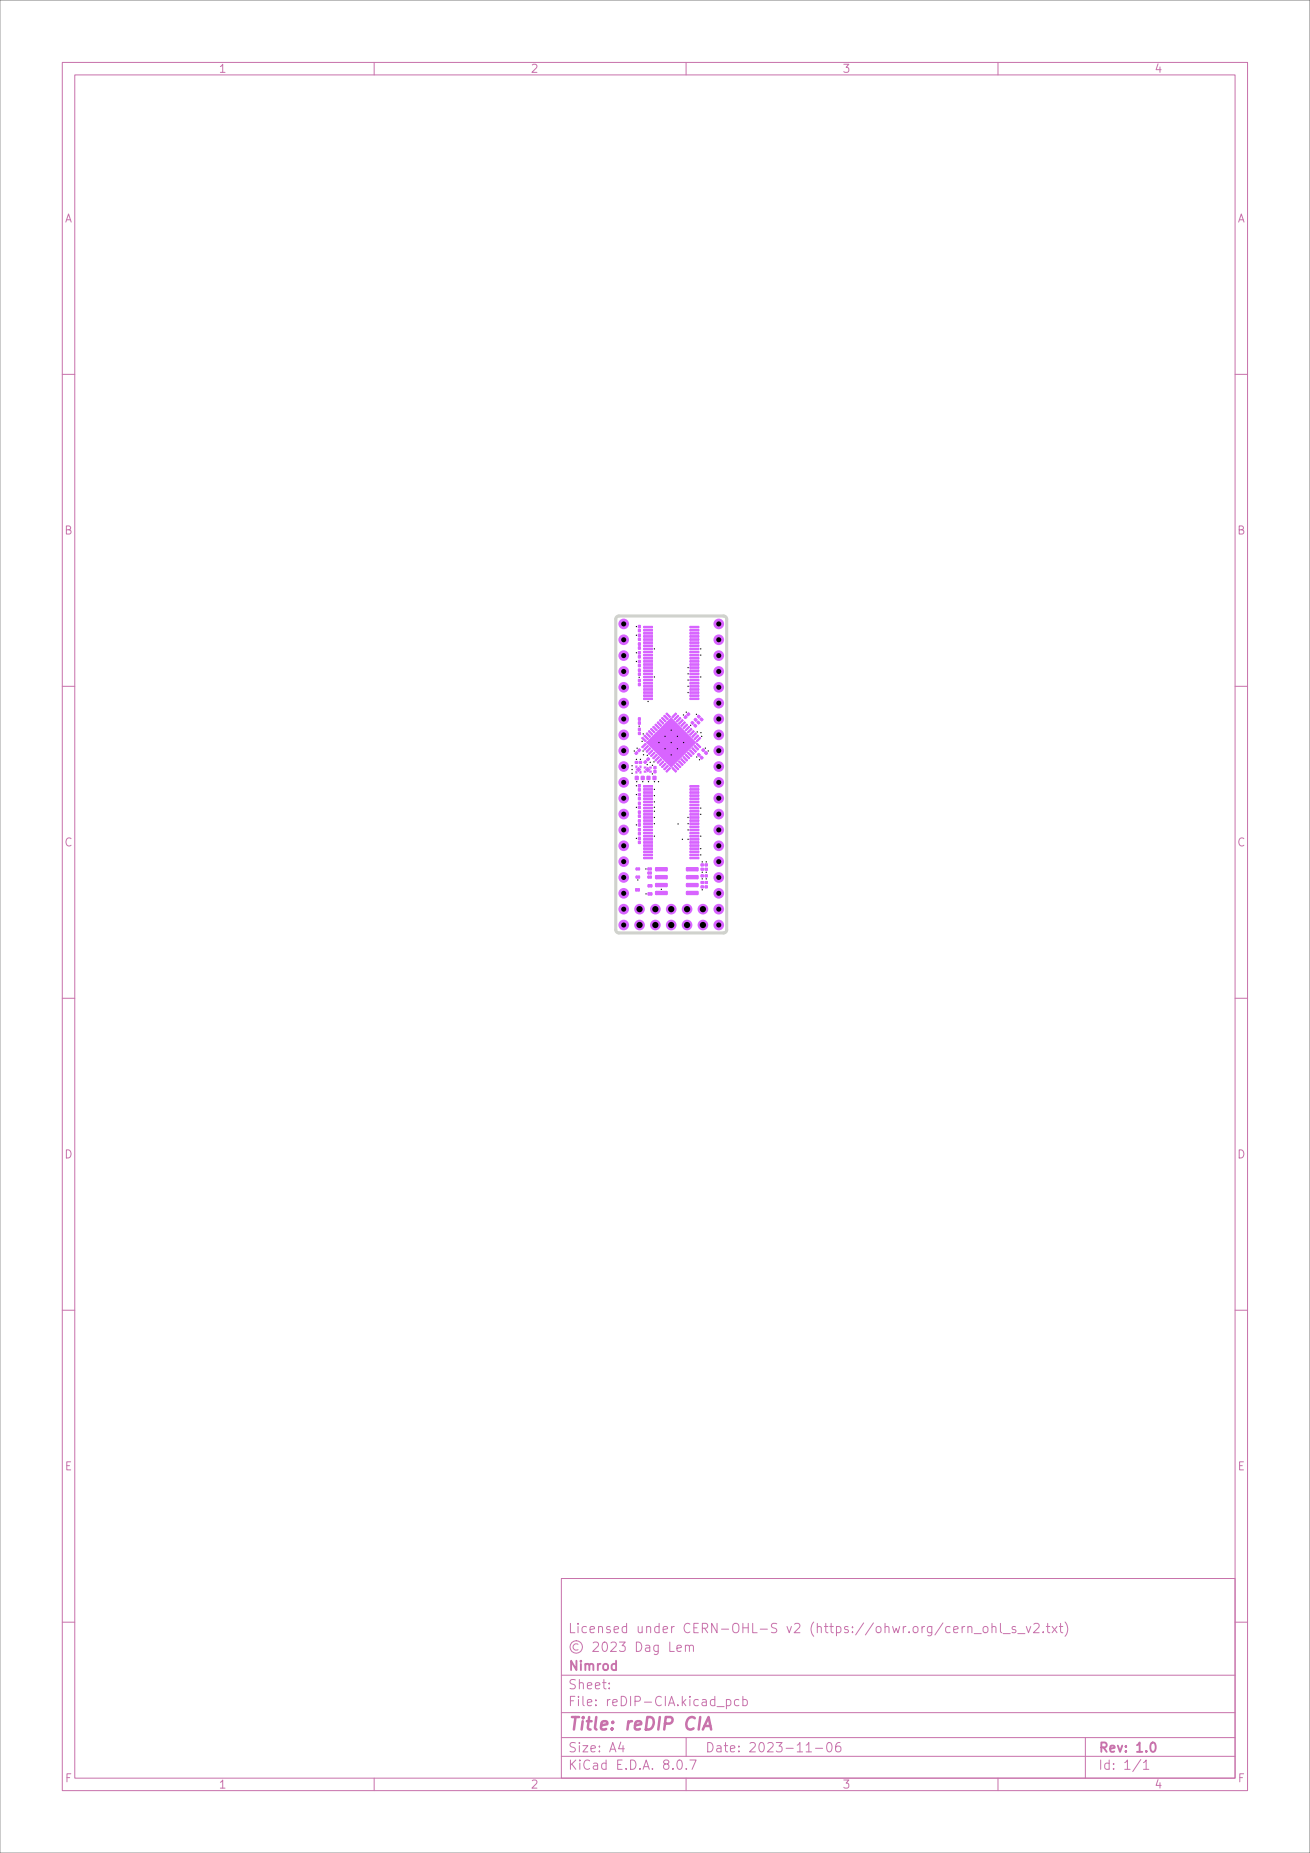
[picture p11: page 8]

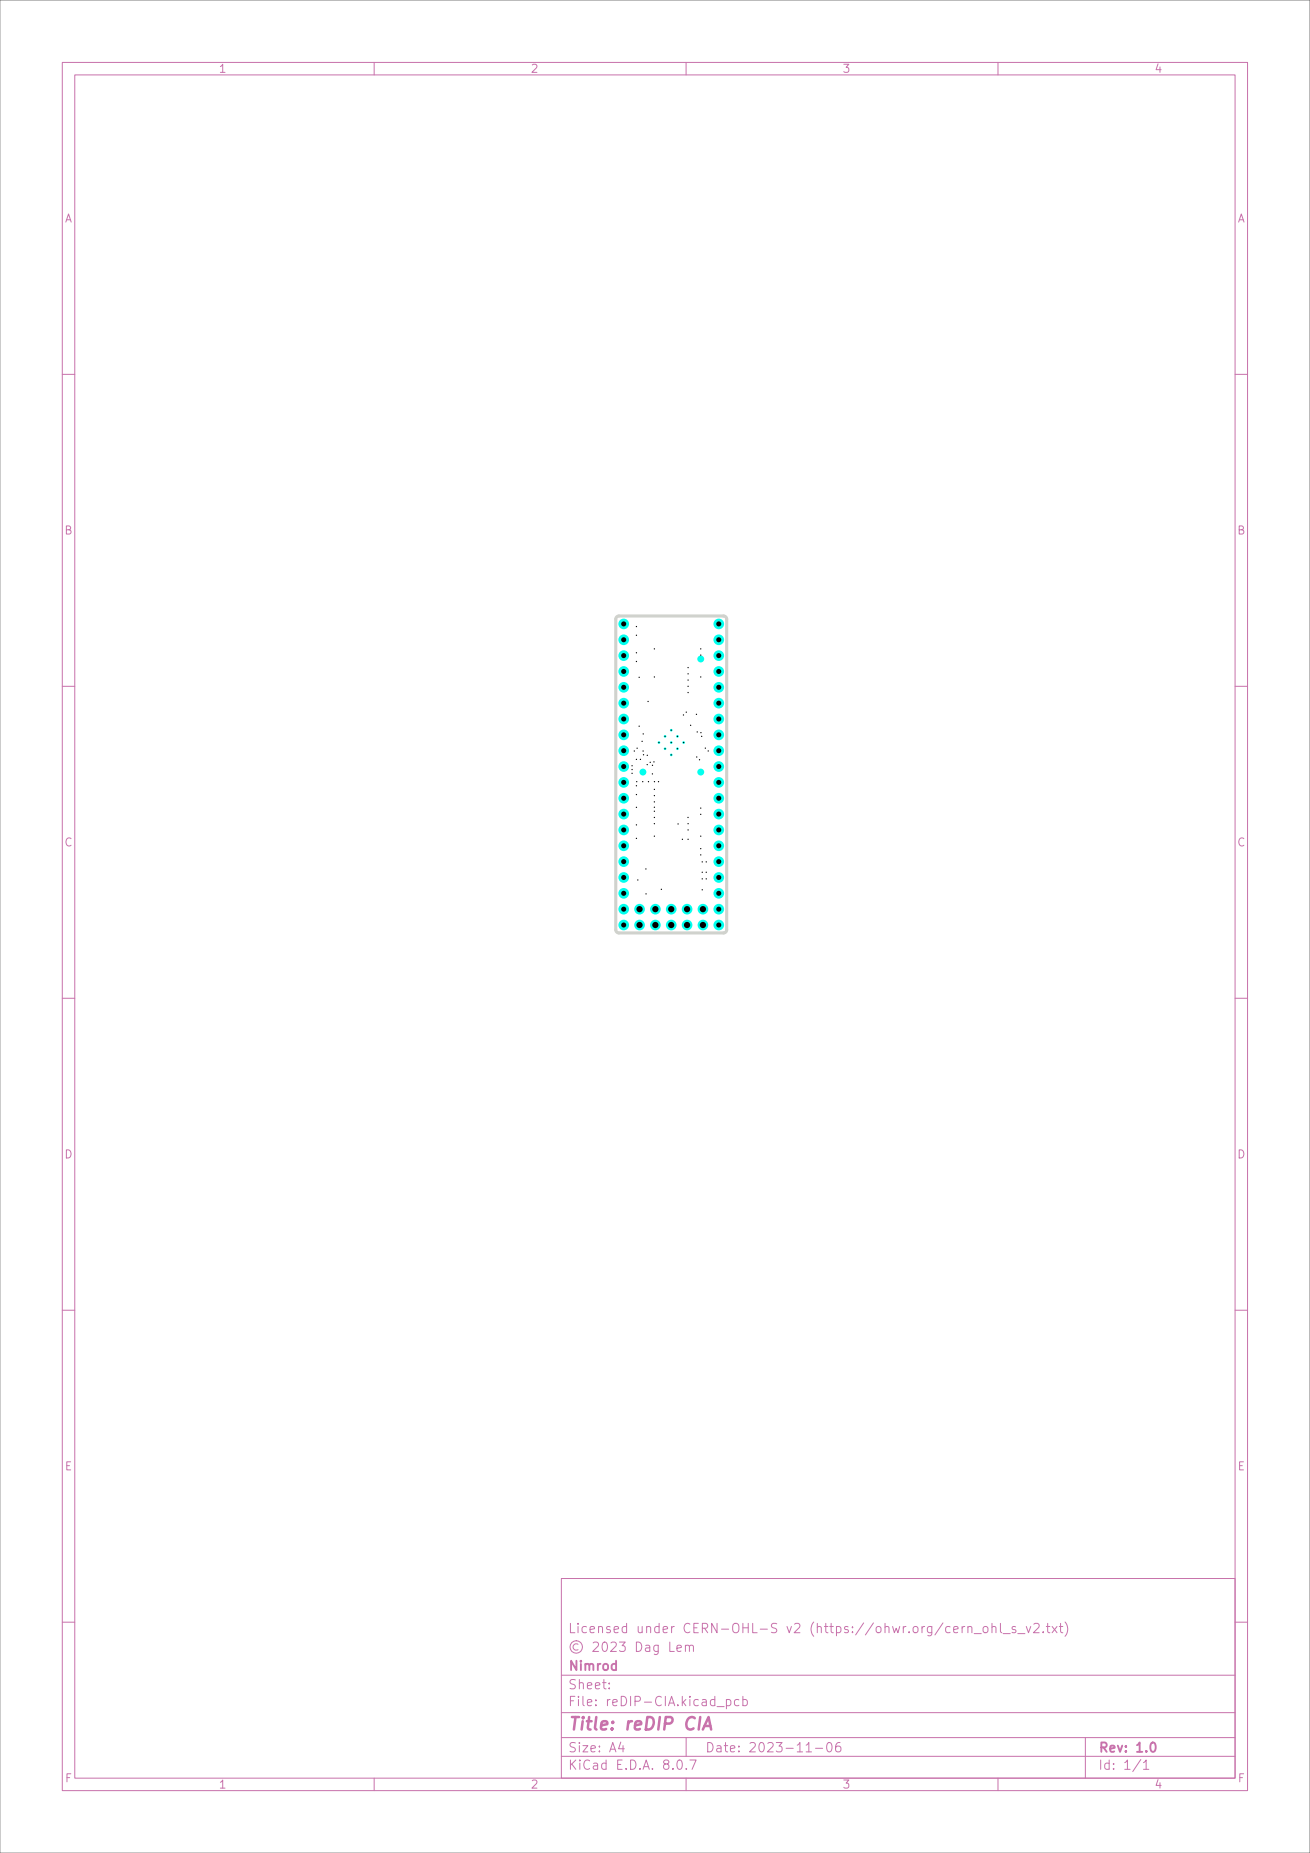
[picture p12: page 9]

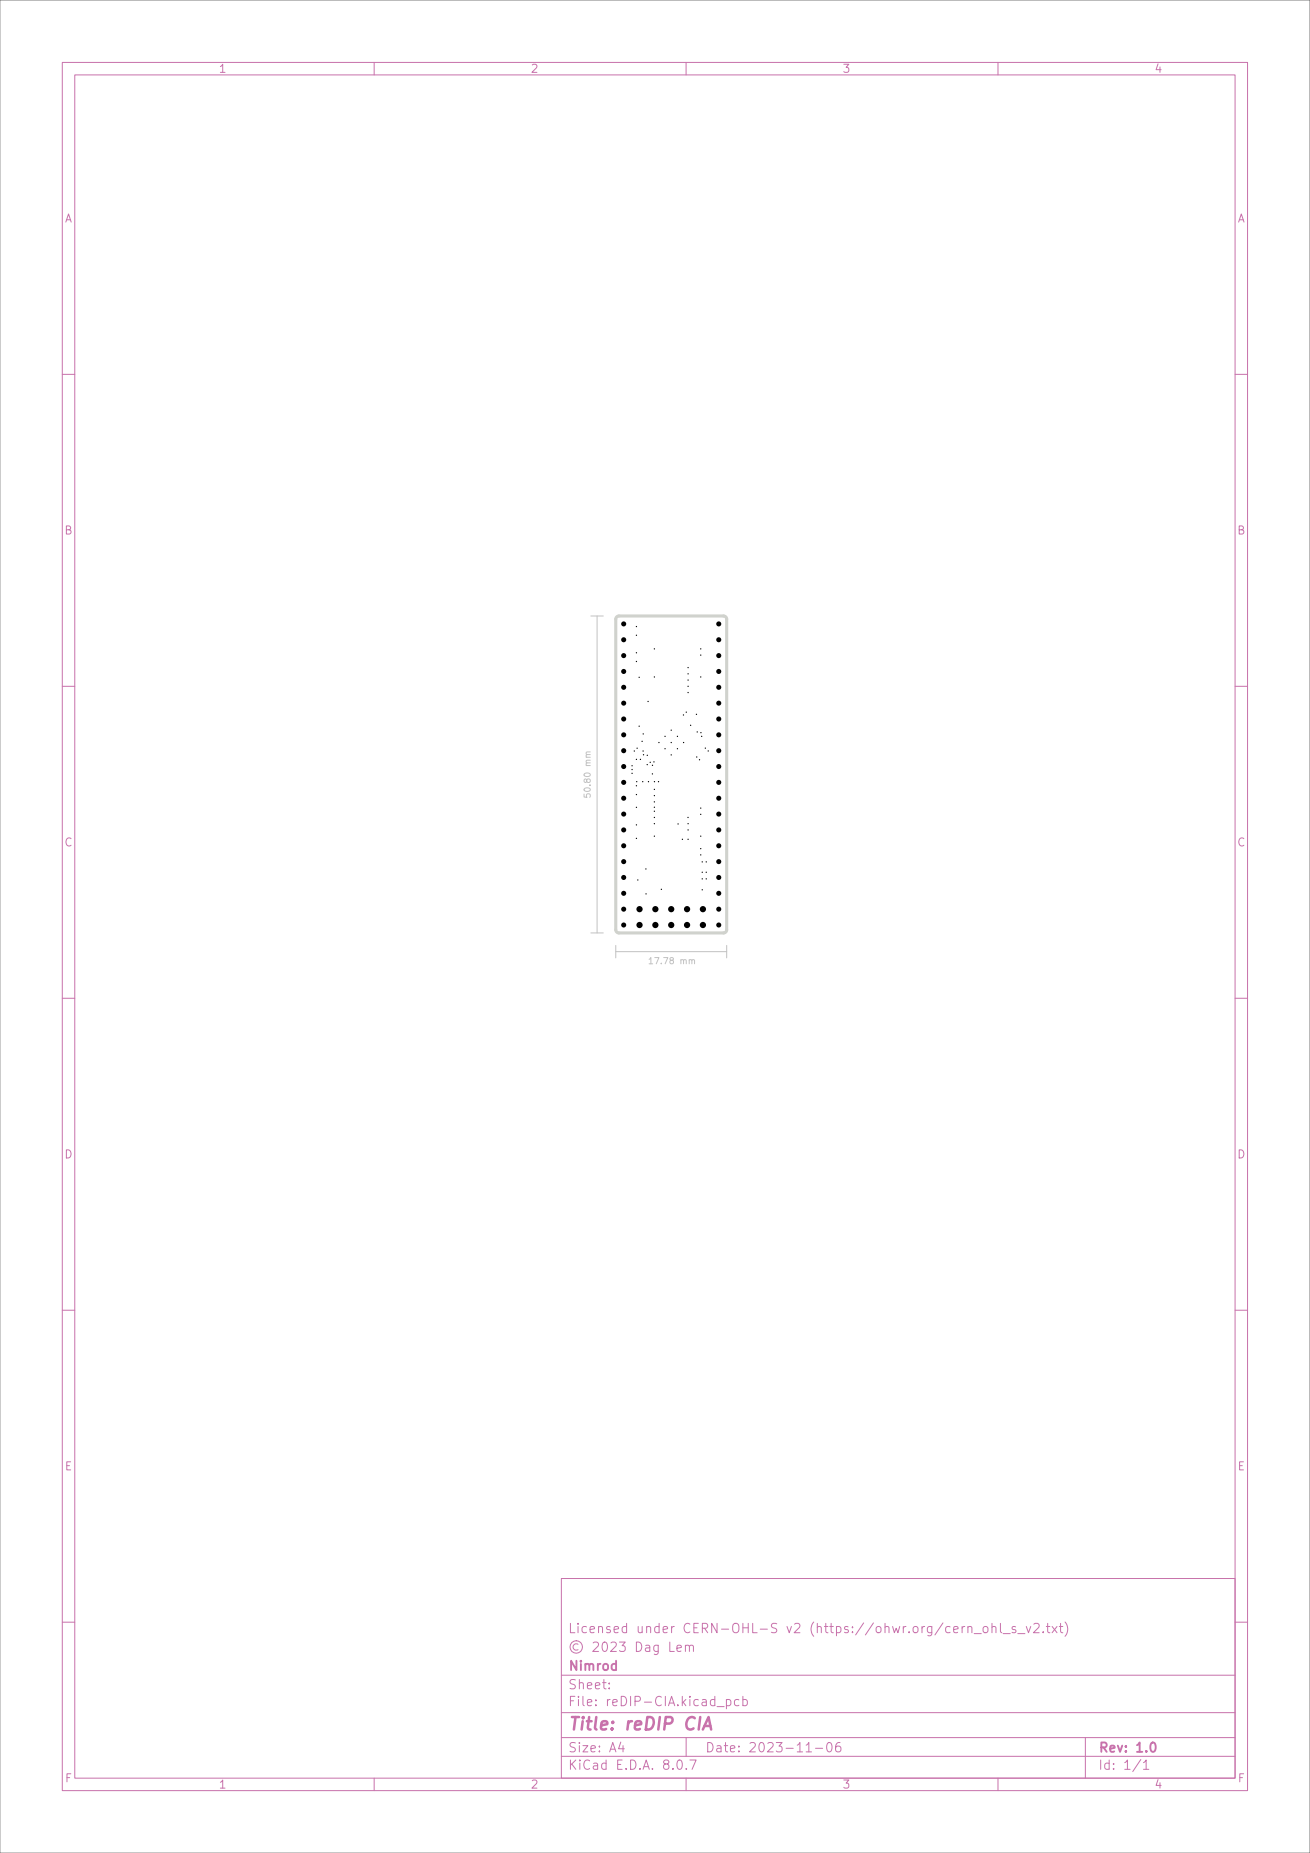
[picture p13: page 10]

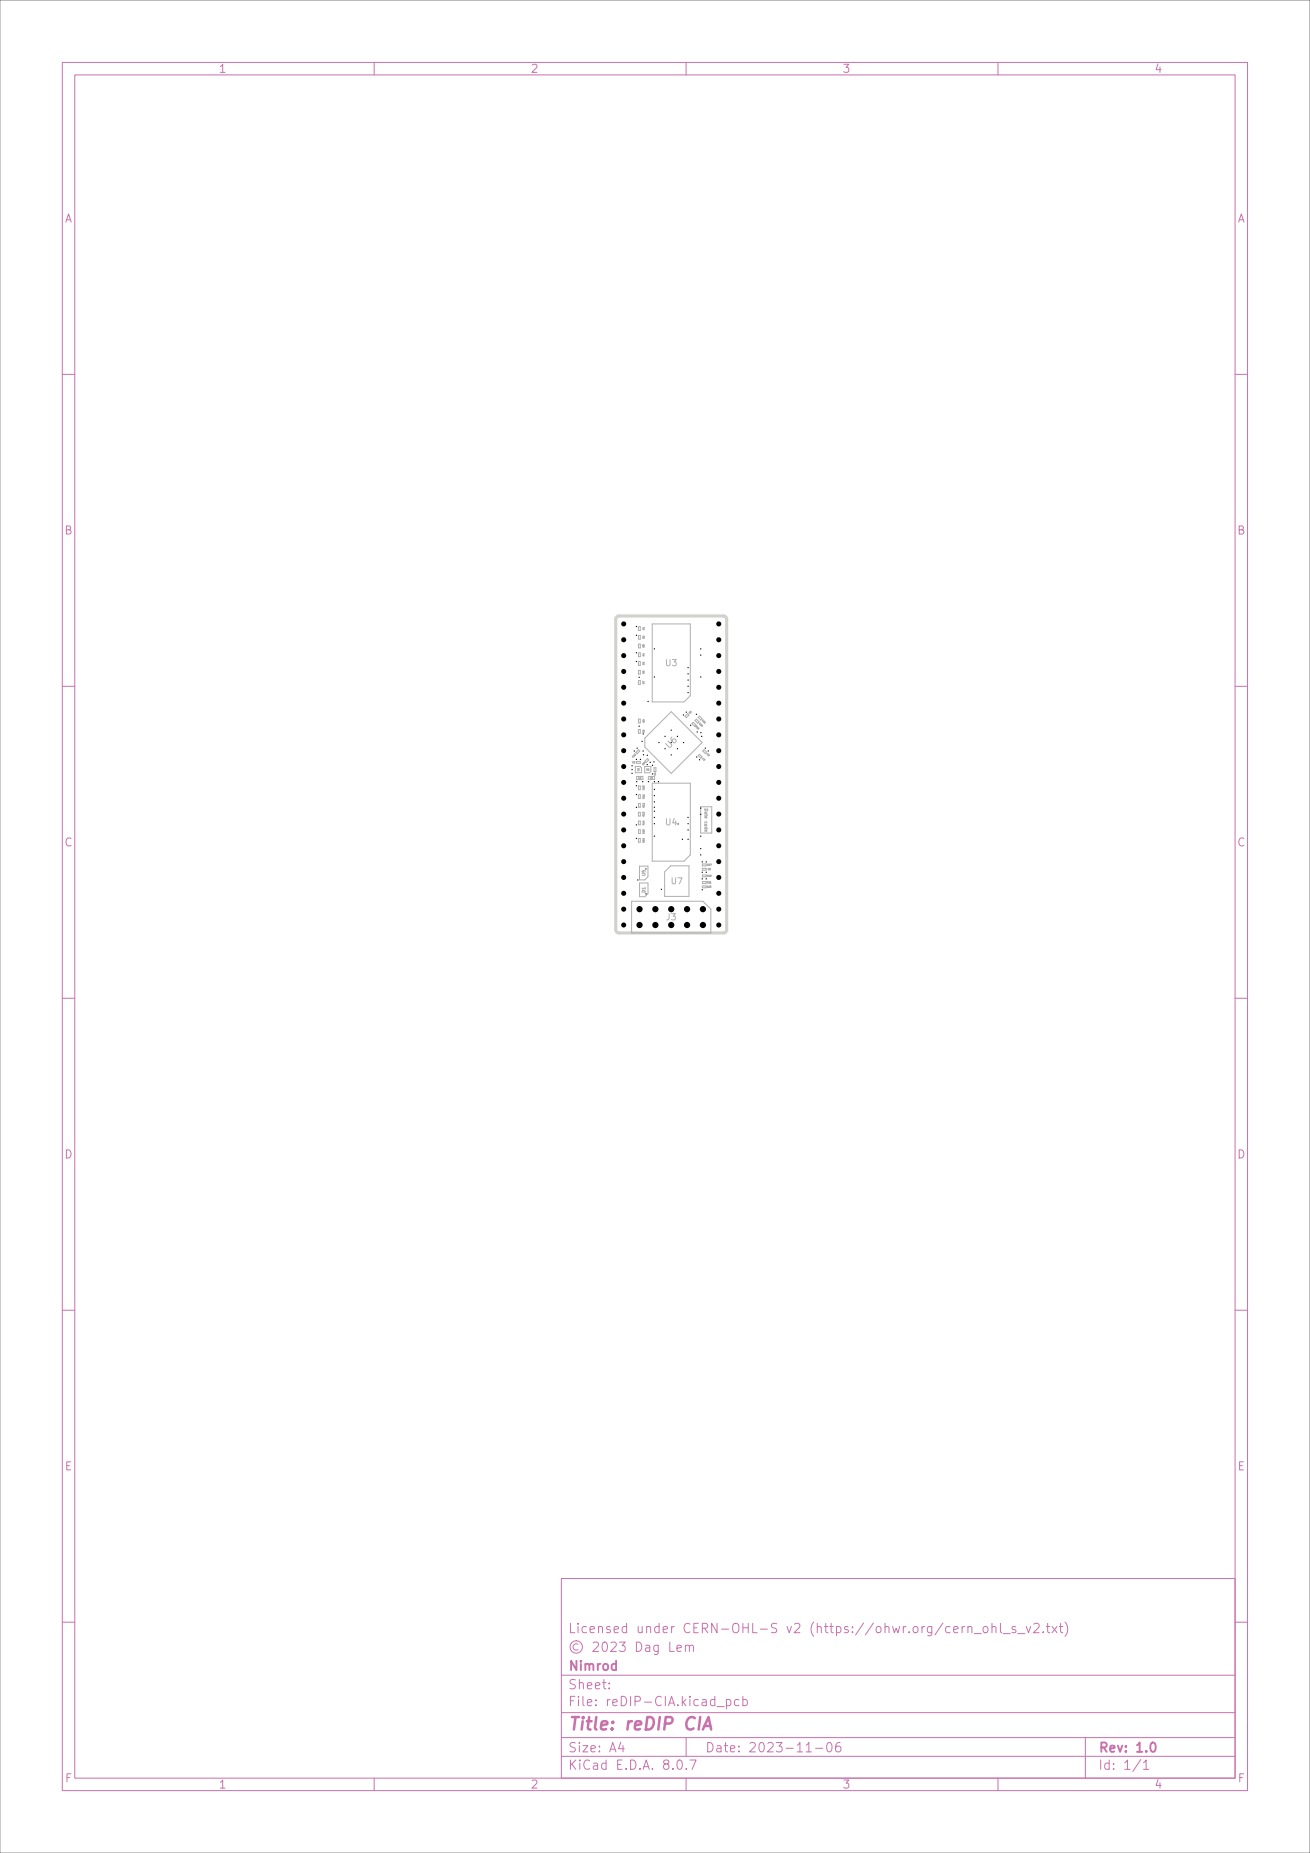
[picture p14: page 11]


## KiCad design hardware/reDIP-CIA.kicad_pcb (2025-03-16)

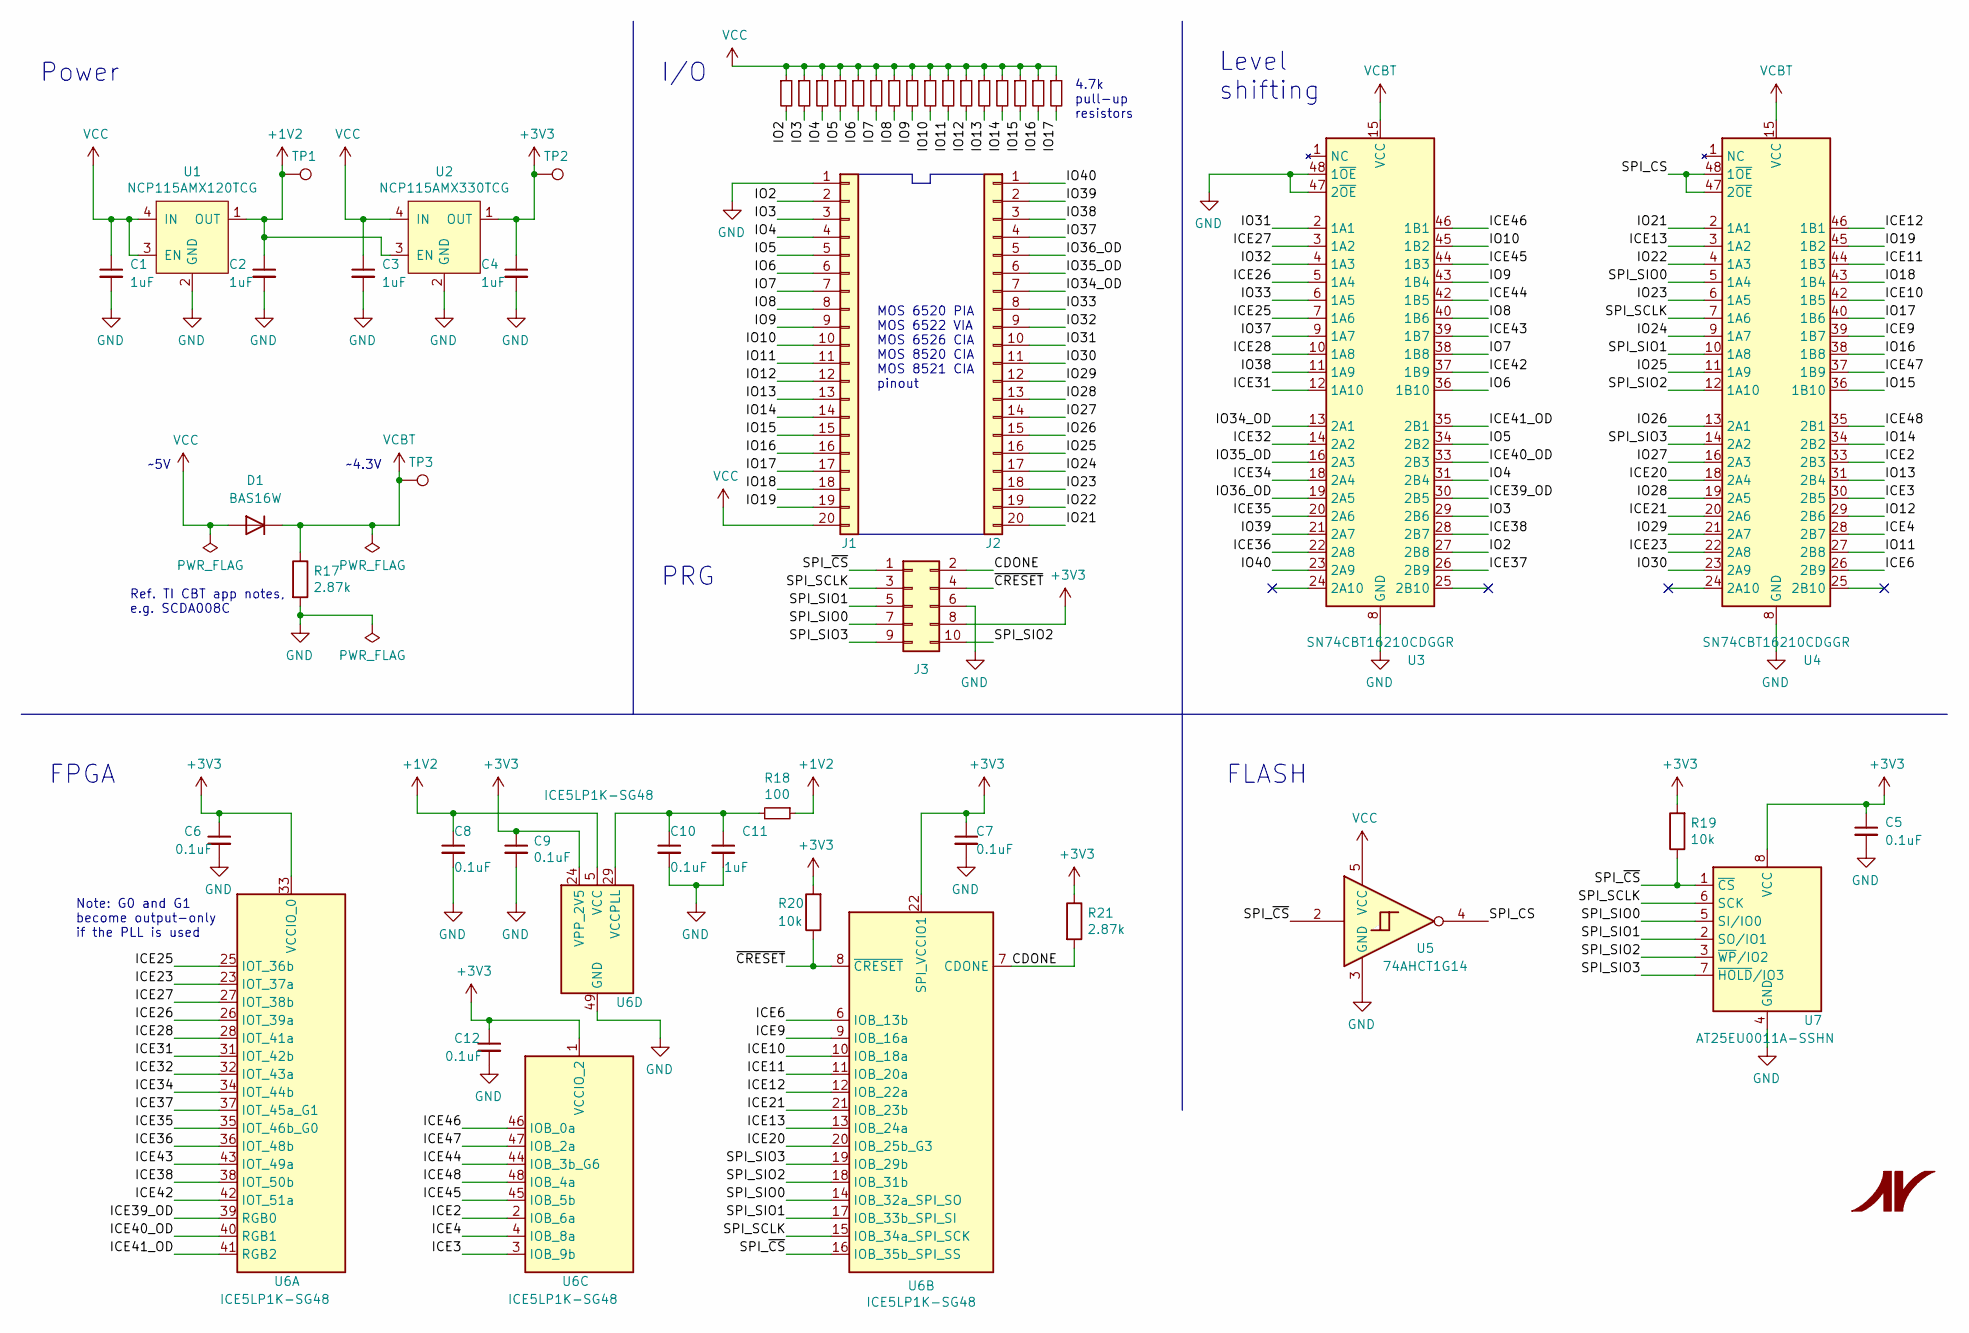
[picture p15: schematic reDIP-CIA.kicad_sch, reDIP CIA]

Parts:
C1, C3: 1uF; C_0402_1005Metric
C2, C4, C11: 1uF; C_0201_0603Metric
C5, C6, C7, C8, C9, C10, C12: 0.1uF; C_0201_0603Metric
D1: BAS16W; SOT-323_SC-70
J1, J2: Conn_01x20; PinHeader_1x20_P2.54mm_Vertical_Machined
J3: Conn_02x05_Odd_Even; PinHeader_2x05_P2.54mm_Vertical
R1, R2, R3, R4, R5, R6, R7, R8, R9, R10, R11, R12, R13, R14, R15, R16: 4.7k; R_0201_0603Metric
R17, R21: 2.87k; R_0201_0603Metric
R18: 100; R_0201_0603Metric
R19, R20: 10k; R_0201_0603Metric
TP1, TP2, TP3: TestPoint; TestPoint_Pad_D1.00mm
U1: NCP115AMX120TCG; CASE_711AJ_1.0x1.0mm_P0.65mm
U2: NCP115AMX330TCG; CASE_711AJ_1.0x1.0mm_P0.65mm
U3, U4: SN74CBT16210CDGGR; TSSOP-48_6.1x12.5mm_P0.5mm
U5: 74AHCT1G14; SOT-353_SC-70-5
U6: ICE5LP1K-SG48; QFN-48-1EP_7x7mm_P0.5mm_EP5.6x5.6mm
U7: AT25EU0011A-SSHN; SOIC-8_3.9x4.9mm_P1.27mm

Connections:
+1V2: C2.1, C8.1, R18.1, TP1.1, U1.1 (OUT), U2.3 (EN), U6.5 (VCC), U6.30 (VCC)
+3V3: C4.1, C5.1, C6.1, C7.1, C9.1, C12.1, J3.8, R19.2, R20.2, R21.1, TP2.1, U2.1 (OUT), U6.1 (VCCIO_2), U6.22 (SPI_VCCIO1), U6.24 (VPP_2V5), U6.33 (VCCIO_0), U7.8 (VCC)
/CDONE: J3.2, R21.2, U6.7 (CDONE)
/ICE2: U4.33 (2B3), U6.2 (IOB_6a)
/ICE3: U4.30 (2B5), U6.3 (IOB_9b)
/ICE4: U4.28 (2B7), U6.4 (IOB_8a)
/ICE6: U4.26 (2B9), U6.6 (IOB_13b)
/ICE9: U4.39 (1B7), U6.9 (IOB_16a)
/ICE10: U4.42 (1B5), U6.10 (IOB_18a)
/ICE11: U4.44 (1B3), U6.11 (IOB_20a)
/ICE12: U4.46 (1B1), U6.12 (IOB_22a)
/ICE13: U4.3 (1A2), U6.13 (IOB_24a)
/ICE20: U4.18 (2A4), U6.20 (IOB_25b_G3)
/ICE21: U4.20 (2A6), U6.21 (IOB_23b)
/ICE23: U4.22 (2A8), U6.23 (IOT_37a)
/ICE25: U3.7 (1A6), U6.25 (IOT_36b)
/ICE26: U3.5 (1A4), U6.26 (IOT_39a)
/ICE27: U3.3 (1A2), U6.27 (IOT_38b)
/ICE28: U3.10 (1A8), U6.28 (IOT_41a)
/ICE31: U3.12 (1A10), U6.31 (IOT_42b)
/ICE32: U3.14 (2A2), U6.32 (IOT_43a)
/ICE34: U3.18 (2A4), U6.34 (IOT_44b)
/ICE35: U3.20 (2A6), U6.35 (IOT_46b_G0)
/ICE36: U3.22 (2A8), U6.36 (IOT_48b)
/ICE37: U3.26 (2B9), U6.37 (IOT_45a_G1)
/ICE38: U3.28 (2B7), U6.38 (IOT_50b)
/ICE39_OD: U3.30 (2B5), U6.39 (RGB0)
/ICE40_OD: U3.33 (2B3), U6.40 (RGB1)
/ICE41_OD: U3.35 (2B1), U6.41 (RGB2)
/ICE42: U3.37 (1B9), U6.42 (IOT_51a)
/ICE43: U3.39 (1B7), U6.43 (IOT_49a)
/ICE44: U3.42 (1B5), U6.44 (IOB_3b_G6)
/ICE45: U3.44 (1B3), U6.45 (IOB_5b)
/ICE46: U3.46 (1B1), U6.46 (IOB_0a)
/ICE47: U4.37 (1B9), U6.47 (IOB_2a)
/ICE48: U4.35 (2B1), U6.48 (IOB_4a)
/IO2: J1.2, R1.2, U3.27 (2B8)
/IO3: J1.3, R2.2, U3.29 (2B6)
/IO4: J1.4, R3.2, U3.31 (2B4)
/IO5: J1.5, R4.2, U3.34 (2B2)
/IO6: J1.6, R5.2, U3.36 (1B10)
/IO7: J1.7, R6.2, U3.38 (1B8)
/IO8: J1.8, R7.2, U3.40 (1B6)
/IO9: J1.9, R8.2, U3.43 (1B4)
/IO10: J1.10, R9.2, U3.45 (1B2)
/IO11: J1.11, R10.2, U4.27 (2B8)
/IO12: J1.12, R11.2, U4.29 (2B6)
/IO13: J1.13, R12.2, U4.31 (2B4)
/IO14: J1.14, R13.2, U4.34 (2B2)
/IO15: J1.15, R14.2, U4.36 (1B10)
/IO16: J1.16, R15.2, U4.38 (1B8)
/IO17: J1.17, R16.2, U4.40 (1B6)
/IO18: J1.18, U4.43 (1B4)
/IO19: J1.19, U4.45 (1B2)
/IO21: J2.20, U4.2 (1A1)
/IO22: J2.19, U4.4 (1A3)
/IO23: J2.18, U4.6 (1A5)
/IO24: J2.17, U4.9 (1A7)
/IO25: J2.16, U4.11 (1A9)
/IO26: J2.15, U4.13 (2A1)
/IO27: J2.14, U4.16 (2A3)
/IO28: J2.13, U4.19 (2A5)
/IO29: J2.12, U4.21 (2A7)
/IO30: J2.11, U4.23 (2A9)
/IO31: J2.10, U3.2 (1A1)
/IO32: J2.9, U3.4 (1A3)
/IO33: J2.8, U3.6 (1A5)
/IO34_OD: J2.7, U3.13 (2A1)
/IO35_OD: J2.6, U3.16 (2A3)
/IO36_OD: J2.5, U3.19 (2A5)
/IO37: J2.4, U3.9 (1A7)
/IO38: J2.3, U3.11 (1A9)
/IO39: J2.2, U3.21 (2A7)
/IO40: J2.1, U3.23 (2A9)
/SPI_CS: U4.47 (2~OE), U4.48 (1~OE), U5.4
/SPI_SCLK: J3.3, U4.7 (1A6), U6.15 (IOB_34a_SPI_SCK), U7.6 (SCK)
/SPI_SIO0: J3.7, U4.5 (1A4), U6.14 (IOB_32a_SPI_SO), U7.5 (SI/IO0)
/SPI_SIO1: J3.5, U4.10 (1A8), U6.17 (IOB_33b_SPI_SI), U7.2 (SO/IO1)
/SPI_SIO2: J3.10, U4.12 (1A10), U6.18 (IOB_31b), U7.3 (~WP/IO2)
/SPI_SIO3: J3.9, U4.14 (2A2), U6.19 (IOB_29b), U7.7 (~HOLD/IO3)
/SPI_~CS: J3.1, R19.1, U5.2, U6.16 (IOB_35b_SPI_SS), U7.1 (~CS)
/~CRESET: J3.4, R20.1, U6.8 (~CRESET)
GND: C1.2, C2.2, C3.2, C4.2, C5.2, C6.2, C7.2, C8.2, C9.2, C10.2, C11.2, C12.2, J1.1, J3.6, R17.2, U1.2 (GND), U2.2 (GND), U3.8 (GND), U3.17 (GND), U3.32 (GND), U3.41 (GND), U3.47 (2~OE), U3.48 (1~OE), U4.8 (GND), U4.17 (GND), U4.32 (GND), U4.41 (GND), U5.3 (GND), U6.49 (GND), U7.4 (GND)
unnamed: C10.1, C11.1, R18.2, U6.29 (VCCPLL)
VCBT: D1.3 (K), R17.1, TP3.1, U3.15 (VCC), U4.15 (VCC)
VCC: C1.1, C3.1, D1.1 (A), J1.20, R1.1, R2.1, R3.1, R4.1, R5.1, R6.1, R7.1, R8.1, R9.1, R10.1, R11.1, R12.1, R13.1, R14.1, R15.1, R16.1, U1.3 (EN), U1.4 (IN), U2.4 (IN), U5.5 (VCC)

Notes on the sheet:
MOS 6520 PIA MOS 6522 VIA MOS 6526 CIA MOS 8520 CIA MOS 8521 CIA pinout
PRG
Ref. TI CBT app notes, e.g. SCDA008C
~4.3V
FLASH
FPGA
Power
4.7k pull-up resistors
I/O
Level shifting
~5V
Note: G0 and G1 become output-only if the PLL is used

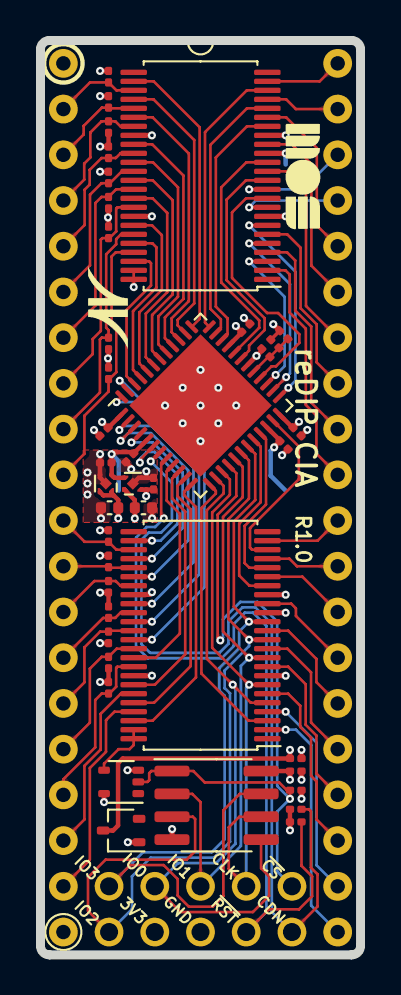
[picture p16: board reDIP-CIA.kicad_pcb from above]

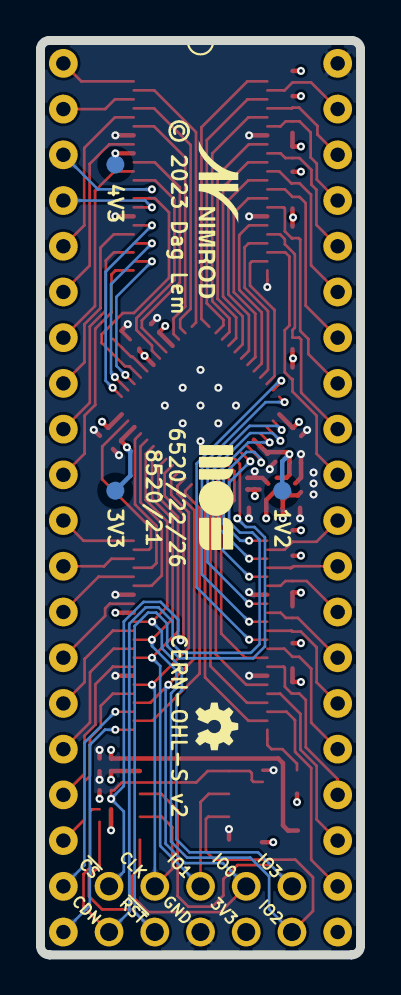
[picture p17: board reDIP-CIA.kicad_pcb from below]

Board: 4 copper layers, 17.8 x 50.8 mm, 56 parts (14 on the bottom side), 86 nets.

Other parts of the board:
SolderMask_D0.25mm, SolderMask_D0.25mm#2, SolderMask_D0.25mm#3, SolderMask_D0.25mm#4, SolderMask_D0.25mm#5, SolderMask_D0.25mm#6, SolderMask_D0.25mm#7, SolderMask_D0.25mm#8, SolderMask_D0.25mm#9: SolderMask_D0.25mm

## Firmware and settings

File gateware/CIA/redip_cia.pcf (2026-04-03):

# MOS 6526 / 8520 / 8521 CIA
# Pin Constraints File for iCE5LP1K-SG48

# CIA pin  1 = VSS
# CIA pin 20 = VCC

# CIA pin 2 - 19
set_io -nowarn PA0  36
set_io -nowarn PA1  35
set_io -nowarn PA2  34
set_io -nowarn PA3  32
set_io -nowarn PA4  31
set_io -nowarn PA5  28
set_io -nowarn PA6  25
set_io -nowarn PA7  26

set_io -nowarn PB0  27
set_io -nowarn PB1  23
set_io -nowarn PB2  21
set_io -nowarn PB3  20
set_io -nowarn PB4  19
set_io -nowarn PB5  18
set_io -nowarn PB6  17
set_io -nowarn PB7  15

set_io -nowarn PC   14
set_io -nowarn TOD  13

# CIA pin 40 - 21
set_io -nowarn CNT  37
set_io -nowarn SP   38
set_io -nowarn RS0  42
set_io -nowarn RS1  43
set_io -nowarn RS2  39
set_io -nowarn RS3  40
set_io -nowarn RES  41

set_io -nowarn D0   44
set_io -nowarn D1   45
set_io -nowarn D2   46
set_io -nowarn D3    6
set_io -nowarn D4    4
set_io -nowarn D5    3
set_io -nowarn D6    2
set_io -nowarn D7   48

set_io -nowarn PHI2 47
set_io -nowarn FLAG  9
set_io -nowarn CS   10
set_io -nowarn R_W  11
set_io -nowarn IRQ  12

# SPI flash pins
set_io -nowarn SPI_CS 16

# Other SPI flash pins are shared as follows:

#   SPI_SIO0 - 14 - PC
#   SPI_SCLK - 15 - PB7
#   SPI_SIO1 - 17 - PB6
#   SPI_SIO2 - 18 - PB5
#   SPI_SIO3 - 19 - PB4

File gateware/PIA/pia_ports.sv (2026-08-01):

// ----------------------------------------------------------------------------
// This file is part of reDIP CIA, a MOS PIA/VIA/CIA FPGA emulation platform.
// Copyright (C) 2025 - 2026  Dag Lem <resid@nimrod.no>
//
// This source describes Open Hardware and is licensed under the CERN-OHL-S v2.
//
// You may redistribute and modify this source and make products using it under
// the terms of the CERN-OHL-S v2 (https://ohwr.org/cern_ohl_s_v2.txt).
//
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
// Source location: https://github.com/daglem/reDIP-CIA
// ----------------------------------------------------------------------------

`default_nettype none

module pia_ports (
    input  logic       clk,
    input  logic       phi2,
    input  logic       res,
    input  logic       cs,
    input  logic       rd,
    input  logic       we,
    input  pia::reg2_t addr,
    input  pia::reg8_t data,
    input  pia::pin_t  ports,
    output pia::regs_t regs,
    output pia::pout_t ports_o,
    output logic       irqa_n,
    output logic       irqb_n
);
    // Registers.
    pia::reg8_t pra, ddra;
    pia::cr_t   cra;
    pia::reg8_t prb, ddrb;
    pia::cr_t   crb;

    // Control lines
    logic ca1_flag;
    logic ca2_flag;
    logic cb1_flag;
    logic cb2_flag;
    logic r_hsa;
    logic r_hsb;
    logic w_hsb;
    logic ca2_out;
    logic cb2_out;

    // Address selects
    logic asel_0;
    logic asel_2;

    always_comb begin
        asel_0 = (addr == 'h0);
        asel_2 = (addr == 'h2);
    end

    // Register writes.
    always_ff @(posedge clk) begin
        // PRA
        if (res) begin
            pra  <= '0;
        end else if (we & asel_0 & cra.prsel) begin
            pra  <= data;
        end

        // DDRA
        if (res) begin
            ddra <= '0;
        end else if (we & asel_0 & ~cra.prsel) begin
            ddra <= data;
        end

        // CRA
        if (r_hsa | res) begin
            // Read of PRA.
            cra.irq1 <= '0;
        end else if (ca1_flag) begin
            cra.irq1 <= '1;
        end

        if (cra.c2_mode[2] | r_hsa | res) begin
            // Output mode or read of PRA.
            cra.irq2 <= '0;
        end else if (ca2_flag) begin
            cra.irq2 <= '1;
        end

        if (res) begin
            cra[5:0] <= '0;
        end else if (we && addr == 'h1) begin
            cra[5:0] <= data[5:0];
        end

        // PRB
        if (res) begin
            prb  <= '0;
        end else if (we & asel_2 & crb.prsel) begin
            prb  <= data;
        end

        // DDRB
        if (res) begin
            ddrb <= '0;
        end else if (we & asel_2 & ~crb.prsel) begin
            ddrb <= data;
        end

        // CRB
        if (r_hsb | res) begin
            // Read of PRB.
            crb.irq1 <= '0;
        end else if (cb1_flag) begin
            crb.irq1 <= '1;
        end

        if (crb.c2_mode[2] | r_hsb | res) begin
            // Output mode or read of PRB.
            crb.irq2 <= '0;
        end else if (cb2_flag) begin
            crb.irq2 <= '1;
        end

        if (res) begin
            crb[5:0] <= '0;
        end else if (we && addr == 'h3) begin
            crb[5:0] <= data[5:0];
        end
    end

    // Handshake signals.
    always_ff @(posedge clk) begin
        if (phi2 & ~cs) begin
            r_hsa <= '0;
        end else if (rd & cra.prsel & asel_0) begin
            r_hsa <= '1;
        end

        if (phi2 & ~cs) begin
            r_hsb <= '0;
        end else if (rd & crb.prsel & asel_2) begin
            r_hsb <= '1;
        end

        if (~(phi2 | we)) begin
            w_hsb <= '0;
        end else if (we & crb.prsel & asel_2) begin
            w_hsb <= '1;
        end
    end

    // Control line inputs, setting IRQ flags.
    pia_edgedet ca1_in(
        .clk     (clk),
        .res     (res),
        .phi2    (phi2),
        .pad_i   (ports.ca1),
        .det_pos (cra.c1_mode[1]),
        .flag_i  (cra.irq1),
        .flag_o  (ca1_flag)
    );

    pia_edgedet ca2_in(
        .clk     (clk),
        .res     (res),
        .phi2    (phi2),
        .pad_i   (ports.ca2),
        .det_pos (cra.c2_mode[1]),
        .flag_i  (cra.irq2),
        .flag_o  (ca2_flag)
    );

    pia_edgedet cb1_in(
        .clk     (clk),
        .res     (res),
        .phi2    (phi2),
        .pad_i   (ports.cb1),
        .det_pos (crb.c1_mode[1]),
        .flag_i  (crb.irq1),
        .flag_o  (cb1_flag)
    );

    pia_edgedet cb2_in(
        .clk     (clk),
        .res     (res),
        .phi2    (phi2),
        .pad_i   (ports.cb2),
        .det_pos (crb.c2_mode[1]),
        .flag_i  (crb.irq2),
        .flag_o  (cb2_flag)
    );

    // Control line outputs.
    always_ff @(posedge clk) begin
        if ((cra.c2_mode[1:0] == 'b00 && cra.irq1) ||         // Handshake on read - reset CA2 high with an active transition on CAl.
            (cra.c2_mode[1:0] == 'b01 && (phi2 & ~r_hsa)) ||  // Pulse output mode - reset CA2 high after a read of PRA.
            (cra.c2_mode[1:0] == 'b11) ||                     // Manual output mode - CA2 held high.
            ~cra.c2_mode[2])                                  // Input mode
        begin
            ca2_out <= '1;
        end else if (cra.c2_mode[1:0] == 'b10 ||              // Manual output mode - CA2 held low.
                     (~phi2 & r_hsa))                         // Handshake on read - set CA2 low following a read of PRA.
        begin
            ca2_out <= '0;
        end

        if ((crb.c2_mode[1:0] == 'b00 && crb.irq1) ||         // Handshake on write - reset CB2 high with an active transition on CBl.
            (crb.c2_mode[1:0] == 'b01 && (phi2 & ~w_hsb)) ||  // Pulse output mode - reset CB2 high after a write of PRB.
            (crb.c2_mode[1:0] == 'b11) ||                     // Manual output mode - CB2 held high.
            ~crb.c2_mode[2])                                  // Input mode
        begin
            cb2_out <= '1;
        end else if (crb.c2_mode[1:0] == 'b10 ||               // Manual output mode - CB2 held low.
                     (phi2 & w_hsb))                           // Handshake on write - set CB2 low following a write of PRB.
        begin
            cb2_out <= '0;
        end
    end

    // Port outputs.
    always_comb begin
        ports_o.pa     = pra;
        ports_o.ddra   = ddra;
        ports_o.pb     = prb;
        ports_o.ddrb   = ddrb;
        ports_o.cb2    = cb2_out;
        ports_o.ca2    = ca2_out;
        ports_o.ddrcb2 = crb.c2_mode[2];

        // IRQ and IRQ enable.
        irqa_n = ~((cra.irq1 & cra.c1_mode[0]) | (cra.irq2 & cra.c2_mode[0]));
        irqb_n = ~((crb.irq1 & crb.c1_mode[0]) | (crb.irq2 & crb.c2_mode[0]));
    end

    // Register outputs.
    always_comb begin
        regs.pra = cra.prsel ? ports.pa : ddra;
        regs.cra = cra;
        // Read Port B outputs back in.
        regs.prb = crb.prsel ? ((~ddrb & ports.pb) | (ddrb & prb)) : ddrb;
        regs.crb = crb;
    end
endmodule

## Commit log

2023-11-07 Added pin constraints files
2025-01-12 Upgrade to KiCad 8
    [reDIP-CIA.kicad_pcb, reDIP-CIA.kicad_sch]
2025-01-12 Add teardrops back again
    Teardrops were lost in conversion to KiCad 8.
    [reDIP-CIA.kicad_pcb]
2025-03-16 Manufacture updates
    [reDIP-CIA.kicad_pcb]
2025-04-08 Fix various issues revealed by simulation
    Fixes all over the place, getting closer to correct MOS 8521 emulation.
    The serial port and MOS 6526 interrupts still need some work.
2025-11-09 Tweak output order of interrupts in simulation
2026-01-14 All serial port tests are now passing in simulation
    This took a lot of effort! The VICE cia-sdr-icr tests don't actually
    test the contents of the ICR register after switching SP MODE from
    OUTPUT to INPUT, and consequently emulators don't get this right.
    A new test will be added to https://sourceforge.net/p/vice-emu/bugs/1219/
2026-01-17 All TOD tests are now passing in simulation
    It is not possible to map out all cycle accurate behavior of the TOD in
    an unmodified C64, since the TOD input is fed from an external signal.
    Hence, emulators do not currently sport cycle accurate TOD behavior.
    The following flags can be provided to the simulation in order to match
    the behavior of emulators:
    * TOD_PHI20_NODELAY: Use PHI2 instead of PHI2/4 for internal clocking
    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
2026-01-27 Correct timer outputs on port B
2026-01-29 Correct timer toggle outputs on port B
2026-02-25 The MOS 8521 gateware now passes all tests
    A lot of effort again! A couple of strange things are going on in the
    interrupt block. Referring to the 8521 schematic at
    http://forum.6502.org/viewtopic.php?f=4&t=7418 - a missing metal contact
    to VCC makes an inverter in the path to IFR_CLR always output 0, and
    extremely long polysilicon gate strips cause delays in driving the ICR
    register output bits to 0. That's my theory, at least :-)
    Also, the 8521 schematic is missing transparent latches gating the
    INT_ACT output.
2026-03-07 The MOS 6526 gateware now passes all tests
    The final pieces finally fell into place when I managed to make sense of
    the ICR block in the die shot at
    http://siliconpr0n.org/archive/doku.php?id=mcmaster:mos:6526
2026-07-30 Include assembled C64 CIA configuration program
2026-08-01 Correct polarity of PIA interrupt signals
    [pia_ports.sv]
2026-08-08 VIA powerup values
2026-08-08 Correct VIA Timer 2 underflow
2026-08-08 Correct reset of VIA IFR bit 6 (Time-out of Timer 1)
2026-08-08 Correct VIA Timer 1 PB7 output
2026-09-05 Synchonize VIA rd with addr at the start of Φ2
    This avoids spurious reads of the previous addr value.
    Thanks to @m1nl for hunting down the bug and proposing a fix.

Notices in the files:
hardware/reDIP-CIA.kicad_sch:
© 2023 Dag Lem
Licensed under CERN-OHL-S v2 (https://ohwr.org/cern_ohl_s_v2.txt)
